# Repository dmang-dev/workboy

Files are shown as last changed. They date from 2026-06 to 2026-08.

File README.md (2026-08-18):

# WorkBoy — a modern, buildable recreation

An open recreation of Nintendo's unreleased **Game Boy WorkBoy** keyboard
accessory (Source R&D / Fabtek / Montague‑Weston, 1992): a QWERTY keyboard that
plugs into the Game Boy Link Port and turns the console into a PDA, plus a
software cartridge.

This repo contains a complete, **buildable and CI‑verified** design — firmware,
a clean‑room ROM, a DRC‑clean PCB, a 3D‑printed case, and an assembly‑ready BOM.

> **Status:** `python tests/run_ci.py` is green — 16 protocol checks + ROM,
> firmware, and case builds. The PCB autoroutes to **0 DRC violations**.

## What's here
| Path | What |
|---|---|
| [`BUILD_PLAN.md`](BUILD_PLAN.md) | the full engineering plan (start here) |
| [`WORKBOY_PROTOCOL.md`](WORKBOY_PROTOCOL.md) | the link‑port byte protocol + scan‑code table |
| `layout/` | single source of truth for the 53‑key layout (`keymap.py`) |
| `firmware/` | ATmega328P keyboard firmware (PlatformIO / avr‑gcc) |
| `rom/` | clean‑room GBDK cartridge: notepad, clock, calculator, phone book |
| `kicad/` | netlist, placed+routed board, Gerbers, CPL — see [`PCB_README.md`](kicad/PCB_README.md) |
| `case/` | parametric enclosure (OpenSCAD + build123d) |
| `tests/` | `protocol_sim.py` + `run_ci.py`; CI in `.github/workflows/` |

## Build & test
```sh
python tests/run_ci.py     # runs every check whose toolchain is installed
```
Toolchains: GBDK‑2020 (ROM), PlatformIO + avr‑gcc (firmware), build123d (case),
KiCad 10 + Freerouting (PCB). See [`BUILD_PLAN.md`](BUILD_PLAN.md) and
[`kicad/PCB_README.md`](kicad/PCB_README.md) for the full pipelines.

## How it works (one paragraph)
The Game Boy is the serial master on the link port; the WorkBoy keyboard is a
passive slave that returns one scan‑code byte per poll. So the "custom PCB" is a
small **5 V ATmega328P keyboard‑matrix controller** that speaks the documented
WorkBoy serial protocol — no level shifter needed. The protocol/scan‑codes were
reverse‑engineered by shonumi (GBE+) and re‑verified here against the real ROM.

## Console compatibility

**One 5 V design covers every console that can run a Game Boy / Game Boy Color
cartridge** — including the GBA and GBA SP, whose link port switches to **5 V**
when an 8‑bit cartridge is inserted. Only the cable plug varies.

| Works | Doesn't |
|---|---|
| DMG‑01, Pocket, Light, Color, GBA, GBA SP | **Game Boy Micro** (GBA‑only, can't run GB/GBC carts) · **Super Game Boy** (no link port) |

Full table, cable choices, and why this is **not** split into per‑console repos:
[`COMPATIBILITY.md`](COMPATIBILITY.md).

> ⚠️ GBA/SP support is documented behaviour that this project has **not yet
> verified on a bench**. Measure before trusting it.

## What you'll need to build one

Nothing here is exotic. Rough 2026 USD; the board is most of the cost.

**Console side**
| Item | Why | ~$ |
|---|---|---|
| A Game Boy that runs GB/GBC carts | the target console — see the compatibility table above | — |
| Flash cart + microSD (EZ-Flash Junior, EverDrive GB, …) | runs `rom/workboy_homebrew.gb`. SD-backed saves mean the phone book persists with **no cart battery** | 25–70 |
| A cheap DMG/GBC link cable to cut | the plug end *is* the connector — see below | 5–8 |

**The keyboard board**
| Item | Why | ~$ |
|---|---|---|
| Bare PCB from JLCPCB, qty 10 | zip up `kicad/gerber/` and upload it. ~$19.60 + shipping | 48 |
| Components per [`workboy_jlcpcb_bom.csv`](workboy_jlcpcb_bom.csv) | one 100-pc lot of each resistor value covers the run. The ATmega is 55 % of it | 39 |
| ~60× 6×6 mm THT tact switches (LCSC **C42416249**) | the 53 keys + spares. ⚠️ *Not* C720477 — that is an SMD 4×3 mm part and will not fit | 2 |
| 2×3 2.54 mm pin header | the ISP header (J2), for flashing | 1 |
| M2.5 brass heat-set inserts + screws | fasten the printed clamshell | 10 |
| *(optional)* blank tactile keycaps | nicer than printed; legends are non-standard anyway | 6 |

Ordering **10 boards** costs $86.50 all-in ($8.65/board) versus $59.75 for 5 —
28 % cheaper per board, because the engineering fee and shipping don't scale.

**Tools**
- **An ISP programmer.** An **Arduino Uno running the stock ArduinoISP sketch** is
  the cheapest route and doubles as the breadboard prototype MCU (it's a 5 V
  ATmega328P, so it talks to the DMG link directly). A USBasp works too.
  ⚠️ **An ST-Link will not work** — it speaks SWD/JTAG/SWIM, and the ATmega needs
  ISP. `firmware/platformio.ini` already ships a commented `stk500v1` block for
  the Arduino-as-ISP path.
- **A logic analyzer** (any cheap 8-channel 24 MHz sigrok/PulseView clone, ~$10) —
  verifying the SPI handshake and clock edge is the single most useful bring-up check.
- Soldering iron, solder, flux · breadboard + dupont wires · 3D printer + PETG/PLA.

**The link connector — the one part with no catalog option**
There is no reliably-purchasable bare DMG link plug. Either **cut a third-party
link cable** (most reliable — keep the 4 used wires SO/SI/SC/GND, and *meter them
before soldering*: the two ends are deliberately cross-wired, so one end's SO is
the other's SI), or **3D-print the plug** — e.g. svender's
[DMG link cable plug](https://www.thingiverse.com/thing:6924711), which uses 6 pins
harvested from female USB sockets. Breakout PCBs exist but still need a cable.

**Suggested order of purchase.** Buy the logic analyzer and a link cable first and
run the P0/P1 protocol test on a breadboard — prove the handshake before spending
on the PCB. Order boards, switches and inserts only once that works.

## Licence

**MIT** — see [`LICENSE`](LICENSE). Attribution, scope, and what is deliberately
*not* in this repo are recorded in [`NOTICE`](NOTICE).

## Legal

This is an independent, unofficial recreation. It is **not affiliated with,
endorsed by, or connected to Nintendo**, Source R&D, Fabtek, or Montague‑Weston.
"WorkBoy" and "Game Boy" are used descriptively to identify the device being
recreated and the consoles it attaches to.

The original WorkBoy ROM is leaked, copyrighted Nintendo‑licensed code — it is
**not** included here and must not be committed or distributed. The cartridge
software in `rom/` is **clean‑room**, written from the documented wire protocol.
Use the leaked ROM only for private bench reference.

The WorkBoy trademark (USPTO 74239332, filed 1992) was **abandoned in 1994**
without ever registering, and both original companies are defunct — see
[`NOTICE`](NOTICE).

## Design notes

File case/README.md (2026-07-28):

# WorkBoy case (parametric, OpenSCAD)

A starter two-piece clamshell — top plate with key cutouts + bottom tray with
PCB standoffs, heat-set screw bosses, and a rear cable slot. Defaults to
~150 × 85 mm to match the original WorkBoy footprint.

## Render / export
Install [OpenSCAD](https://openscad.org/), open `workboy_case.scad`, set `part`
and press **F6**, or from the command line:
```sh
openscad -D 'part="top"'    -o workboy_top.stl    workboy_case.scad
openscad -D 'part="bottom"' -o workboy_bottom.stl workboy_case.scad
```

## The key field is generated — do not hand-edit it

Plate cutouts come from **`layout/keymap.py`**, the single source of truth, via
`layout/gen_layout.py` → **`case/key_positions.scad`**. `workboy_case.scad`
`include`s that file and cuts one rectangle per key at its real centre, scaling
each by its own width in key units. The build123d port imports the same data
directly (`from keymap import centers`).

So both case models already carry the **real 53-key layout**: rows of
**12 / 11 / 11 / 11 / 8**, 52 keys at 1u plus the **5u space bar**, on a
12 × 5 unit field at 12 mm pitch (144 × 60 mm).

**After changing `keymap.py`, re-run the generator** or the case silently drifts
from the PCB:
```sh
python layout/gen_layout.py    # rewrites key_positions.scad, scancode_map.h, keymap.svg, key_positions.json
python tests/run_ci.py
```

## Key parameters (top of the file)
| Param | Meaning |
|---|---|
| `pitch` | key center-to-center spacing (mm) — **must match `PITCH` in `gen_layout.py`** |
| `key_gap` | plate cutout = key cell minus this (cap clearance) |
| `key_pos[]` | **generated** — `[cx, cy, width_units]` per key, origin = case centre |
| `case_h`, `wall`, `plate_th`, `floor_th` | shell dimensions |
| `standoff_h` | PCB rest height (clears THT lead tails) |
| `insert_d` | heat-set insert pocket dia — **verify against your inserts** |

## This is a starting point — refine before printing
1. **Keycap interface:** holes are sized for floating caps captured by the plate.
   Tune `cap_clear` with a one-row fit-test print before committing 53 holes.
3. **Material:** PETG for the shell (survives heat-set inserts and a warm
   console); resin for crisp legended keycaps.
4. **Fasteners:** M2.5 brass heat-set inserts in the bosses, screws from the top.
   For hidden screws, flip to inserts-in-plate / screws-from-bottom (Scheme B in
   BUILD_PLAN §5).
5. **Cable:** the rear slot is for a soldered link pigtail; add a printed strain
   relief or grommet.

## build123d model — **the board file is the single source of truth**

[`workboy_case_b123d.py`](workboy_case_b123d.py) is the maintained model. It exports
`workboy_top.stl`, `workboy_bottom.stl` and a combined `workboy_case_assembly.step`.

**Every dimension is parsed from `kicad/workboy.kicad_pcb` at build time** — the
outline, the four mounting-hole positions, the key pitch and the key-field offset.
Nothing is hard-coded, so the case cannot drift from the PCB. Change the board,
re-run this, done.

```sh
python -m venv .venv && .venv/bin/pip install build123d   # never install system-wide
python workboy_case_b123d.py
```

It refuses to export if the board does not fit, and reports the numbers it used:

```
board  : 152.000 x 106.125 mm, centre (150.0000, 89.0625) [from workboy.kicad_pcb]
case   : 160.000 x 114.125 x 22.000 mm outer
         155.200 x 109.325 mm interior (1.6 mm clearance per side)
key    : pitch 12.0 mm measured from the board; field offset (+0.0000, +19.0625)
mounts : 4 at (-72.000,-49.063), (-72.000,+49.062), (+72.000,-49.063), (+72.000,+49.062)
```

For the visual assembly it also imports `kicad/workboy_board.step` if present, and
checks that the board centres, that the through-hole leads clear the floor and that
the tallest part clears the top plate. Generate that STEP with:

```sh
kicad-cli pcb export step --output kicad/workboy_board.step kicad/workboy.kicad_pcb
```

> ⚠️ There used to be a `kicad/make_board_step.py` that produced a **placeholder
> rectangle** into that same path — and CI ran it, so it silently overwrote the real
> export. It has been removed. If you find it referenced anywhere, that reference is
> stale; use the `kicad-cli` line above.

> **The key field is not centred on the board.** The PCB carries a ~48 mm
> electronics strip below the last key row, so the key field sits **+19.0625 mm**
> from the board centre. `keymap.centers()` is origin-centred on the *key field*;
> the case is centred on the *board*. The script derives that offset from the real
> switch coordinates rather than assuming it.

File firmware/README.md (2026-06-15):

# WorkBoy keyboard firmware (ATmega328P)

Bare-metal AVR firmware that makes the controller PCB act as the WorkBoy
keyboard: a passive **SPI slave** on the Game Boy link, plus an 8×7 matrix scan.
Protocol contract: [`../WORKBOY_PROTOCOL.md`](../WORKBOY_PROTOCOL.md). Pin map:
[`../kicad/KICAD_NETLIST.md`](../kicad/KICAD_NETLIST.md).

## Pin map (matches `kicad/workboy.net`)
- **Rows** ROW0–7 = **PORTD** (PD0–PD7) — driven LOW one at a time, others hi-Z.
- **Cols** COL0–5 = PC0–PC5, COL6 = PB0 — inputs with internal pull-ups.
- **Link SPI** /SS PB2, MOSI PB3, MISO PB4, SCK PB5 (Mode 1, MSB-first).
- **LEDs** PB6 (CAPS), PB7 (NUM). **Reset** PC6. **Spare** PB1.

## Build / flash (PlatformIO)
```sh
pio run            # build
pio run -t fuses   # internal 8 MHz RC + BOD 2.7 V (needed so PB6/PB7 are GPIO)
pio run -t upload  # flash via USBasp on the ISP header (J2)
```
Program **before** attaching the link cable — the ISP pins are shared with the
link SPI lines.

No PlatformIO? Build with avr-gcc directly:
```sh
avr-gcc -mmcu=atmega328p -DF_CPU=8000000UL -Os -Wall -o workboy.elf workboy_keyboard.c
avr-objcopy -O ihex workboy.elf workboy.hex
avrdude -c usbasp -p m328p -U flash:w:workboy.hex
# fuses: internal 8 MHz, BOD 2.7 V
avrdude -c usbasp -p m328p -U lfuse:w:0xE2:m -U hfuse:w:0xD9:m -U efuse:w:0xFD:m
```

## What to verify on first bring-up
1. **SPI edge:** the code uses Mode 1 (CPOL=0, CPHA=1). If the Init reply comes
   back rotated on a logic analyzer, flip `CPHA` (see `spi_slave_init`) to Mode 3.
2. **No-key value & modifier model:** `WB_NOKEY` and the toggle-vs-shift model are
   `#define`s at the top of `workboy_keyboard.c`. Defaults match the GBE+/leaked-ROM
   convention; flip to SameBoy's (`0xFF`, held-shift) only if the real ROM rejects
   input.
3. **Matrix:** fill `SCANCODE[ROWS][COLS]` to your physical key wiring; the diode
   orientation (anode→COL) must match the scan direction (drive ROW low, read COL).

## Status
`workboy_keyboard.c` is complete and self-contained: SPI-slave state machine,
1 ms debounced matrix scan, 1 Hz software RTC, and the GPIO layer wired to the
netlist. The two things to finalize per your build are the physical `SCANCODE`
legend map and (optionally) lighting the CAPS/NUM LEDs.

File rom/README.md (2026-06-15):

# WorkBoy homebrew ROM (clean-room)

A **legally distributable** Game Boy cartridge that drives the recreated WorkBoy
keyboard over the link port. Built only from the documented wire protocol
([`../WORKBOY_PROTOCOL.md`](../WORKBOY_PROTOCOL.md)) — it contains **no leaked
Nintendo code or assets**.

> This is a **bring-up demo / foundation**, not the full 12-app suite. It proves
> the keyboard works end-to-end: link handshake, a notepad that echoes typed
> characters, NUM-mode toggling, and an RTC timestamp from the keyboard's clock.
> Extend it app-by-app from here.

## Files
| File | Role |
|---|---|
| `src/workboy_link.c/.h` | GB **master**-side link driver (the 4 commands) |
| `src/scancodes.c/.h` | scan-code → ASCII map (kept identical to the firmware) |
| `src/phonebook.c/.h` | **phone book stored in the 32 KB battery SRAM** (add / list / scroll) |
| `src/main.c` | home: notepad + clock + `App-7` opens the phone book |
| `Makefile` | GBDK-2020 build → `workboy_homebrew.gb` (MBC1+RAM+BATTERY) |

> **Builds clean** with GBDK-2020 → a 128 KB MBC1+RAM+BATTERY image (verified
> header: cart `0x03`, 128 KB ROM, 32 KB SRAM). The phone book uses MBC1
> RAM-banking mode across all four 8 KB banks (128-byte records, up to 255
> entries) and persists on a battery-backed cart.

## Build
1. Install **GBDK-2020** (<https://github.com/gbdk-2020/gbdk-2020/releases>).
2. Build, pointing at your install:
   ```sh
   make GBDK_HOME=/opt/gbdk          # Linux/macOS
   make GBDK_HOME=C:/gbdk            # Windows (forward slashes)
   ```
3. Output: `workboy_homebrew.gb`.

## Run
- **EverDrive GB / EZ-Flash Jr.:** copy `workboy_homebrew.gb` to the microSD and
  pick it from the menu. Saves use the cart's battery SRAM.
- **Repro cart:** flash to an **MBC1 + RAM + BATTERY** cartridge (the Makefile sets
  cart type `0x03`, 32 KB SRAM). A no-mapper 32 KB cart will **not** work.
- Connect the recreated keyboard to the link port, power it (USB-C/battery), and
  reset. You should see `Keyboard: OK`, then typing echoes on screen; press the
  Clock app-key to print the time.

## Protocol notes baked in
- GB is the **master** (internal clock, `SC_REG = 0x81`). Responses are pipelined
  by one transfer — `wb_poll_key()` polls twice and returns the second byte.
- Commands: `0x52` Init→`0x44`, `0x4F` Poll→scancode, `0x44` Read-RTC→42 bytes,
  `0x57` Write-RTC (not used by this demo).
- `wb_xfer()` has a spin-guard so a missing/unpowered keyboard can't hang the ROM.

## Validate on a logic analyzer first
If the handshake fails on real hardware, check the SPI edge convention against the
keyboard firmware (Mode 1 vs Mode 3) and confirm the keyboard's no-key value is
`0x00` (GBE+) — both are `#define`-switchable on the firmware side.

## Extending toward the full suite
Add apps as screens driven by the app-launch scancodes (`0x01`–`0x09`). Persist
data in the 32 KB battery SRAM (`ENABLE_RAM`, write to `0xA000`+ banks). Re-create
the calculator / phone book / calendar logic from scratch — do **not** copy the
leaked ROM's code or data.

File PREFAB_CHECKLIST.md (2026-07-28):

# Pre-fabrication checklist

**Can I order a board yet?** Work down this list. Anything marked 🔴 will cost you
a board if you skip it.

> **Status: not yet ordered. Nothing here has been built.** Everything below is
> from design review, not from an assembled unit.

> ### Verification pass 2026-07-28
>
> The three original blockers were investigated against the real KiCad files with
> `kicad-cli` 10.0.5 and `pcbnew`. **Two were false alarms. The third is worse than
> written.** Two new blockers were found that were not on the list at all.
>
> **The bare PCB is electrically sound and could be fabricated today** — DRC is
> genuinely clean (0 violations, 0 unconnected, 886 tracks, 60 vias) and every net
> checked lands where the netlist says. What blocks an order is **mechanical**:
> no mounting holes, and a case built to the wrong size.
>
> Confidence is *not* uniform below — each item says how it was established.

---

## 🔴 Blocking — fix before uploading gerbers

### 1. ~~The board has no mounting holes at all~~ ✅ **RESOLVED 2026-07-28 — four added**

*Was: `grep -c MountingHole` → 0, while `BUILD_PLAN` promised 4× M2.5 and the case
drilled four standoffs. The placeholder's holes at (±61, ±28.5) were fictional.*

Four `MountingHole:MountingHole_2.7mm_M2.5` (**plain NPTH, no copper**) are now
placed, 4.0 mm inset from the `Edge.Cuts` centreline at each corner, symmetric
about the board centre **(150.0, 89.0625)**:

| Ref | Corner | Position (mm) |
|---|---|---|
| **H1** | top-left | **(78.000, 40.000)** |
| **H2** | top-right | **(222.000, 40.000)** |
| **H3** | bottom-left | **(78.000, 138.125)** |
| **H4** | bottom-right | **(222.000, 138.125)** |

**Hole spacing: 144.000 × 98.125 mm** — these are the numbers the case standoffs
must use.

Positions were chosen by scanning clearances against every pad, track, via and part
body. Insets of 4.0–5.5 mm all pass; **6.0 mm fails** because the top-right hole
starts fouling **SW12**. 4.0 mm was taken as it maximises component clearance at
that tightest corner:

| | copper clr | part-body clr | edge clr |
|---|---|---|---|
| H1 | 7.071 mm (SW1) | 6.329 mm | 4.000 mm |
| **H2** | **4.607 mm (SW12)** | **4.475 mm** ← tightest | 4.000 mm |
| H3 | 9.318 mm (R11) | 9.071 mm | 4.000 mm |
| H4 | 24.934 mm (J3) | 22.674 mm | 4.000 mm |

A 5 mm case post needs 2.5 mm of body clearance, so the worst case leaves **1.98 mm
of margin**. Hole edge sits 2.65 mm from the board edge.

**Verified after the change:**
- `kicad-cli pcb drc --severity-all --exit-code-violations` → **0 violations, 0
  unconnected, 0 footprint errors**, exit 0
- Board outline **unchanged** (73.925–226.075 × 35.925–142.200 incl. stroke)
- Drill file carries tool **`T6C2.700` with exactly 4 hits** at those coordinates
- Holes are marked exclude-from-BOM and exclude-from-position-files, so the **CPL
  still lists 131 parts** and `workboy_jlcpcb_bom.csv` is byte-unchanged
- H1–H4 added to `generate_workboy_netlist.py` (135 components, zero net nodes) so
  a future netlist re-import **cannot silently delete them**

> ⚠️ The right-hand edge only has **2.05 mm** of free border (J3 runs close to it) —
> there is no room for a fifth hole mid-span on that side. The corners are the only
> viable positions.

### 2. ~~The case is sized for 144 × 78~~ ✅ **RESOLVED 2026-07-28 — case rebuilt from the board**

*Was: three different board sizes in the docs and none of them right. The case
interior was **155.2 × 71.2 mm** for a **152.000 × 106.125 mm** board — it overran
by 34.9 mm in depth and was 30 mm deeper than the case's whole outer envelope. The
placeholder never fitted either, so the model was unvalidated, not merely stale.*

`case/workboy_case_b123d.py` was rewritten to **parse `kicad/workboy.kicad_pcb` at
build time**. The outline, the four mounting-hole positions, the key pitch and the
key-field offset are all read from the board — nothing is hard-coded, so the case
cannot drift from the PCB again. It **refuses to export** if the board does not fit.

| | Old | New |
|---|---|---|
| Outer | 160 × 76 × 22 mm | **160.000 × 114.125 × 22.000 mm** |
| Interior | 155.2 × 71.2 mm | **155.200 × 109.325 mm** |
| vs board 152.000 × 106.125 | ✗ 34.9 mm short | ✅ **1.600 mm clearance per side** |
| Standoffs | (±61, ±28.5) — matched no real hole | **(±72.000, ±49.0625)** = H1–H4 |
| Sized from | key field | **the board outline** |

**Verified independently** (re-derived from the board and the exported solids, not
from the script's own claims):

- **Key cutout alignment: worst mismatch 0.000000 mm across all 53 keys.** Every
  cutout is centred on its switch.
- Board centring error **0.0000 mm** in both axes.
- **4.095 mm** of air under the protruding through-hole leads (they reach 1.905 mm
  below the PCB — the old model never accounted for them).
- **1.865 mm** headroom between the tallest part (18.135 mm) and the top plate.
- `tests/run_ci.py` → `case-export PASS`.

Two things the rewrite had to fix beyond size:

- **The key field is not centred on the board.** There is a ~48 mm electronics strip
  below the last key row, so the field sits **+19.0625 mm** from the board centre.
  `keymap.centers()` is origin-centred on the *key field*, the case on the *board*.
  The offset is now derived from the real switch coordinates.
- **Screw bosses and PCB standoffs had to merge.** With 1.6 mm of clearance there is
  no room for separate corner bosses beside a board that fills the interior — they
  would collide with it. One M2.5 screw per corner now passes through the top plate,
  through the PCB hole, into an insert in the boss, so the same fastener closes the
  case and retains the board. The clearance scan behind §1 already proved a 7 mm
  boss fits at all four holes.

> 🔴 **`kicad/make_board_step.py` has been deleted, and this mattered.** It wrote a
> placeholder rectangle to `kicad/workboy_board.step` — **and `tests/run_ci.py` ran
> it on every CI run**, silently overwriting the real exported board with a 144 × 78
> rectangle. Regenerate the real one with:
> ```sh
> kicad-cli pcb export step --output kicad/workboy_board.step kicad/workboy.kicad_pcb
> ```

> ⚠️ **Remaining case work is connector access, not fit** — see §7.

### 3. ~~J3 USB-C pad names are unverified~~ ✅ **RESOLVED — false alarm**
*Established with `pcbnew` against the placed footprint, and by diffing the board's
footprint copy against the KiCad 10 library `.kicad_mod`. This item had full
adversarial review; nothing was overturned.*

The old text was wrong on both counts. The netlist never used GCT `USB4085` naming
(`generate_workboy_netlist.py:44` declares
`Connector_USB:USB_C_Receptacle_HRO_TYPE-C-31-M-12`, which is exactly what is placed
at `workboy.kicad_pcb:4783`), and the shield is called **`SH`** in both — no
KiCad 10 `Connector_USB` footprint uses an `S1` pad at all.

All 10 referenced pad names exist and carry the intended net:

| Net | Pads |
|---|---|
| GND | A1, A12, B1, B12, + 4× SH |
| VBUS | A4, A9, B4, B9 |
| USB_CC1 / USB_CC2 | A5 / B5 |

Sink topology is valid (5.1 kΩ Rd on both CC lines), and D54's SS14 is oriented
correctly — pad 2 (anode) on VBUS, pad 1 (cathode) on +5 V. `A6/A7/A8/B6/B7/B8`
are intentionally netless: this is a power-only connector and the ATmega328P has no
native USB.

> **Still worth 30 seconds before ordering:** that **LCSC C165948** really is the
> HRO TYPE-C-31-M-12 is a vendor-catalogue fact that cannot be checked from these
> files. Compare the LCSC land pattern against the footprint before you buy.

> **Do not add a 16 MHz crystal later without revisiting D54.** The Schottky drops
> ~0.4–0.5 V, so +5 V sits below VBUS. Harmless now (the MCU runs on its internal
> oscillator — there is no crystal in the netlist), but at 16 MHz a 4.75 V source
> minus the drop falls under the 4.5 V minimum.

### 4. ~~Tact switch pad numbering~~ ✅ **RESOLVED** — but the **BOM part is wrong** 🔴
*⚠️ Confidence caveat: the adversarial reviewers for this item all failed to run
(spend limit). The reasoning below is from a single investigation plus the cited
datasheet — **it has not been independently cross-checked.***

The pad-numbering worry was well founded but the wiring is **correct**.
`SW_PUSH_6mm` in KiCad 10.0.5 does use duplicated numbers (four pads: `1,1,2,2`),
and the grouping is right: same-numbered pads sit **6.5 mm apart** on a common Y
(`SW_PUSH_6mm.kicad_mod:290-315`), matching the Omron B3F terminal arrangement
where the tied legs span the long side. The switch closes across the 4.5 mm gap —
so netlist pads 1 and 2 are genuinely **across the contacts**, not shorted.

Every footprint also carries `(duplicate_pad_numbers_are_jumpers no)`, so KiCad
required real copper between each tied pair rather than trusting the leadframe —
and that copper is present. A single bad solder joint per pair will not kill a key.

✅ **BOM part corrected 2026-07-28 — `C720477` was indeed the wrong part.**

Checked on LCSC: **`C720477` is XUNPU `TS-1088-AR02016`, package "SMD,4x3mm",
surface mount, 2 terminals.** Wrong size, wrong mount type, wrong terminal count —
all 53 switches were specified as a part that cannot be fitted to this footprint.

Replaced with **`C42416249` — SHOU HAN `SH-6X6X8H-CJ`**:

| | |
|---|---|
| Package | **`DIP-4P,6x6mm`** — through-hole, 4 legs |
| **Lead spacing** | **6.5 × 4.5 mm** — matches `SW_PUSH_6mm` exactly |
| Body / height | 6 × 6 mm, 8 mm actuator |
| Life | 100,000 cycles · SPST · 50 mA · 12 V |
| Stock / price | 8,480 · ~$0.0124 ea @ 20+ (≈ **$1.30 for 100**) |

8 mm was chosen because the case already models the switch ~8.5 mm above the PCB.
**The whole SH-6X6X\*H-CJ family shares the identical 6.5 × 4.5 mm footprint** at
4.3 / 5.5 / 6.5 / 8 / 9 mm, so the actuator height can be re-picked when the keycaps
are designed **without touching the board** — only the BOM line changes.

> The `Footprint` column was also wrong (`SW-TH-6.0x6.0`, a name matching nothing);
> it now carries LCSC's own `DIP-4P,6x6mm` string.

#### 🔴 And a second wrong part number: J2

Found while costing the BOM. **`C2718` is an onsemi `FDA50N50` — a 500 V, 48 A
N-channel MOSFET**, not a 2×3 pin header. Confirmed on the LCSC product page
(category *Discrete Semiconductors → Transistors → FETs, MOSFETs*).

Replaced with **`C42431837` — JXTCONN `PH2.54-2X3P-H25`**: category *Headers, Male
Pins*, 2×3 six-pin dual row, 2.54 mm pitch, through-hole, gold-plated, 3 A / 1 kV,
39,180 in stock, **$0.0293 ea @ 20+**.

> **Two of the fourteen BOM lines pointed at parts that could not be fitted.** Both
> were plausible-looking C-codes that nobody had opened. If any other line matters
> to you, open its LCSC page before ordering — the footprints are verified against
> the real land patterns, but a part *number* is only as good as the last person who
> checked it.

### 4b. 🔍 Full BOM audit — **every line opened on LCSC (2026-07-28)**

Prompted by two bad part numbers in a row. All 14 lines checked for *identity,
value, package and availability* — not just existence.

| Line | LCSC | What it actually is | Verdict |
|---|---|---|---|
| U1 ATmega328P-AU | `C14877` | Microchip ATMEGA328P-AU · 5,662 stock · $2.14 | ✅ |
| C1–C4 100nF 0402 | `C1525` | Samsung CL05B104KO5NNNC · 100nF **0402** 16 V X7R · 1.39 M | ✅ |
| C5,C6 10µF 0805 | `C15850` | Samsung CL21A106KAYNNNE · 10µF **0805** 25 V X5R · 295 k | ✅ |
| D1–D53 1N4148W | `C2099` | JSCJ 1N4148W **SOD-123** · 32,050 · $0.0124 | ✅ |
| D54 SS14 | `C2480` | MDD SS14 **SMA** · $0.019 (MOQ 50) | ✅ |
| J3 USB-C | `C165948` | **Korean Hroparts TYPE-C-31-M-12** · 246,285 · $0.17 | ✅ *(also settles §3)* |
| SW1–53 tact | `C42416249` | SHOU HAN SH-6X6X8H-CJ · DIP-4P 6×6 · 8,480 | ✅ *(fixed, §4)* |
| J2 ISP header | `C42431837` | JXTCONN PH2.54-2X3P-H25 · 2×3 male THT · 39,180 | ✅ *(fixed, §4)* |
| R1–R3 10k 0402 | ~~`C25744`~~ → **`C60490`** | was UNI-ROYAL 0402WGF1002TCE — right part, **out of stock** | ✅ **replaced** |
| R4–R6 220R 0402 | ~~`C25091`~~ → **`C112291`** | was UNI-ROYAL 0402WGF2200TCE — right part, **out of stock** | ✅ **replaced** |
| R7–R9 1k 0402 | ~~`C11702`~~ → **`C106235`** | was UNI-ROYAL 0402WGF1001TCE — right part, **out of stock** | ✅ **replaced** |
| R10,R11 5.1k 0402 | ~~`C25905`~~ → **`C105872`** | was UNI-ROYAL 0402WGF5101TCE — right part, **out of stock** | ✅ **replaced** |
| LED1 red "0805" | ~~`C2286`~~ → **`C2295`** | was KENTO **KT-0603R — 0603**, not 0805 | 🔴 **wrong package — fixed** |
| LED2,3 green "0805" | ~~`C72043`~~ → **`C2297`** | was EVERLIGHT 19-217 — **0603** *and* unavailable | 🔴 **wrong package — fixed** |

#### 🔴 Both LEDs were the wrong package

`C2286` and `C72043` are **0603** parts, but the board has **0805** land patterns
(`LED_SMD:LED_0805_2012Metric`). A 0603 body hand-solders onto 0805 pads, but in
reflow it risks tombstoning and misplacement — pick-and-place positions to the
part's own body, not the pad.

Replaced with the same manufacturer's genuine 0805 parts, both well stocked:
**`C2295` KT-0805R** (red, 101,200) and **`C2297` KT-0805G** (green, 1,996,800).

#### ⚖️ The 0402 resistors depend on **who assembles the board**

The two catalogues disagree, and the right part number is different for each path:

| | LCSC retail (hand-buy) | JLCPCB library (PCBA) |
|---|---|---|
| **UNI-ROYAL `0402WGF*TCE`** | ❌ out of stock | ✅ **Basic**, stocked (1.1–2.1 M) |
| **YAGEO `RC0402FR-07*`** | ✅ in stock (0.2–1.4 M) | ⚠️ **Extended** (per-part fee) |

Electrically identical — **0402, ±1 %, 62.5 mW, 50 V, ±100 ppm/℃, thick film** — so
this is purely a sourcing choice.

**`workboy_jlcpcb_bom.csv` carries the UNI-ROYAL parts**, because it is the JLCPCB
*assembly* BOM and `BUILD_PLAN` outsources SMT. JLCPCB sources from its own library,
where these are Basic and in stock, so LCSC's retail shortage is irrelevant and you
avoid four Extended-part fees.

| Ref | Value | PCBA (in the BOM) | Hand-build alternative |
|---|---|---|---|
| R1–R3 | 10 kΩ | **`C25744`** 0402WGF1002TCE | `C60490` RC0402FR-0710KL |
| R4–R6 | 220 Ω | **`C25091`** 0402WGF2200TCE | `C112291` RC0402FR-07220RL |
| R7–R9 | 1 kΩ | **`C11702`** 0402WGF1001TCE | `C106235` RC0402FR-071KL |
| R10,R11 | 5.1 kΩ | **`C25905`** 0402WGF5101TCE | `C105872` RC0402FR-075K1L |

> **If you hand-assemble, swap in the right-hand column** — LCSC cannot sell you the
> left-hand parts today. MOQ there is 100 in multiples of 100, ~$0.55 per value.

> 🪤 **The stock trap:** every LCSC product page has `... | In Stock | LCSC
> Electronics` in its `<title>` as **static SEO boilerplate — even for
> out-of-stock parts**. It fooled this review once. Read stock from the page body,
> where an unavailable part shows "Out of Stock" and a "Notify Me" button instead of
> "Add to Cart".

> **Tally: 8 of 14 lines were wrong.** Four named a part that could not be fitted
> (2 outright wrong parts, 2 wrong package) and four named parts that could not be
> bought. All eight are now corrected and individually verified. The footprints had
> been checked against real land patterns all along — it was the *part numbers* that
> nobody had ever opened.
>
> **Every line is now confirmed against its own LCSC page**, with stock read from
> the page body. No board change came out of any of it: the `.kicad_pcb` carries no
> LCSC part numbers, so the gerbers, drill and CPL were never affected.

### 4c. JLCPCB **Basic vs Extended** — every SMT part checked (2026-07-28)

Extended parts carry a per-unique-part loading fee, so this drives assembly cost
more than the components do. Checked directly in JLCPCB's parts library:

| Part | LCSC | Class | JLC stock | @1+ |
|---|---|---|---|---|
| 100nF 0402 | `C1525` | ✅ **Basic** | 46,782,818 | $0.0053 |
| 10 µF 0805 | `C15850` | ✅ **Basic** | 10,801,486 | $0.1191 |
| SS14 | `C2480` | ✅ **Basic** | 2,084,080 | $0.0189 |
| Green LED 0805 | `C2297` | ✅ **Basic** | 2,977,165 | $0.0162 |
| 10 kΩ 0402 | `C25744` | ✅ **Basic** | — | — |
| 220 Ω 0402 | `C25091` | ✅ **Basic** | — | — |
| 1 kΩ 0402 | `C11702` | ✅ **Basic** | 1,120,826 | — |
| 5.1 kΩ 0402 | `C25905` | ✅ **Basic** | 2,109,090 | — |
| **ATmega328P-AU** | `C14877` | ⚠️ Extended | 29,242 | $2.4159 |
| **1N4148W** ×53 | `C2099` | ⚠️ Extended | 61,717 | $0.0123 |
| **USB-C** | `C165948` | ⚠️ Extended | 264,067 | $0.1843 |
| **Red LED 0805** | `C2295` | ⚠️ Extended | 102,716 | $0.0115 |

**8 Basic, 4 Extended.** Keeping the UNI-ROYAL resistors (§4) rather than the YAGEO
ones cut Extended from 8 to 4 — worth roughly $12 in loading fees, i.e. more than
the bare PCBs cost.

The four that remain are hard to avoid: the MCU, the USB-C receptacle and the
switching diode have no Basic equivalent for this design. Only the **red LED** is
casually swappable — its green sibling `C2297` *is* Basic, so if you want one fewer
Extended line, use a Basic red 0805 or make the power LED green too.

> 🪤 **JLCPCB's page title lies the same way LCSC's does.** Every search renders
> `No Results Found for <code>` into `<title>` **before** the client-side fetch
> returns, then the body fills in with the real hit. Judging by the title reports a
> part as missing when it is right there. This produced a wrong conclusion earlier in
> this very review — the UNI-ROYAL resistors were reported absent from JLCPCB's
> library when they are in fact **Basic and stocked**. Read the body, not the title.

> Cheap physical settle: put a DMM across one switch before soldering 53. The legs
> **6.5 mm** apart must beep **unpressed**; the legs **4.5 mm** apart must be open
> until pressed.

---

## 🟡 Decide before ordering

### 4. Which link connector?

> ### ✅ **FINAL for rev A (2026-07-28): ship J1 only. J4 and J5 are both deferred.**
>
> **This is what the board already is** — `EMIT_LINK_SOCKET` and `EMIT_LINK_EDGE`
> are both `False`, so J4 and J5 have never appeared in any netlist or board. The
> exported gerbers, drill, CPL and BOM in this repo are **correct as they stand and
> need no re-export** for this decision.
>
> **Why J1 only.** J4 is not free in the way it first looked. It costs nothing in
> *board area*, but it does cost a **footprint that does not exist and cannot be
> drawn without the physical part in hand** — you must buy an EXT socket, measure
> it, draw `workboy:GB_EXT_Socket_6P`, re-import, place, route, re-run DRC and
> re-export. That is the entire remaining critical path for rev A, in service of a
> connector whose only benefit over J1 is cable convenience. A soldered pigtail
> works on day one.
>
> **Rev A proves the design; rev B can add the socket** once a real board has shown
> the protocol works end to end — and by then the socket can be measured against a
> board that exists.
>
> **J5 (board-edge tongue) stays parked** for the reasons below: it forces an
> outline change, wants ENIG (**~1.5–2.0×** the bare-board line vs HASL) because an
> inserted edge wears, and — decisively — it plugs the board *rigidly into the
> console with no cable*, which is wrong for a keyboard you sit and type on.
>
> The full analysis for both is kept here and in `generate_workboy_netlist.py`, and
> the netlist support is already written and inert, so revisiting either needs no
> re-research.

**What this means practically:** populate **J1**, a 1×6 0.1″ header, and attach a
cut link cable as a pigtail. Meter it first — see the warning at the end of this
file, reversed SI/SO is a top failure mode.

All three options land on the **same six nets**; you populate exactly one. Wiring
them in parallel would be electrically free — the cost is footprint work, not area.

| | **J1** — 1×6 0.1″ header ✅ **rev A** | **J4** — real EXT socket ⏸ rev B | **J5** — board-edge tongue ⏸ parked |
|---|---|---|---|
| Status | **shipping — on the board now** | needs footprint drawn | needs footprint **+ outline** |
| Attaches via | soldered cut-cable pigtail | **any standard link cable** | plugs straight into the console |
| Part cost | ~$5–8 (cable to cut) | ~$3–10 (repair part) | **$0 — no part** |
| Board outline | unchanged | unchanged | ⚠️ **changes it** |
| Plating | HASL fine | HASL fine | ⚠️ wants **ENIG** or pads wear |
| Thickness | any | any | ⚠️ socket is ~1.2 mm nominal; **1.6 mm is tight** |
| Ergonomics | permanent tail | best — normal cable | rigid, board hangs off the console |

**J4 — deferred to rev B. Notes kept.** It changes nothing about the outline,
plating or thickness, so it can be added later at no cost to the board. What it
needs is a **footprint drawn from a physical socket**, which is why it is not in
rev A.

**J5 — parked. Notes kept for a possible rev B.**

Not free despite costing no parts:

- **Outline change** — the tongue protrudes, so the case must be re-fitted and the
  board edge redrawn.
- **Finish** — ENIG at **~1.5–2.0×** the bare-board line (HASL is JLCPCB's free
  default). Hard "gold fingers" is **~3.0–5.0×** plus bevelling, and is meant for
  thousands of insertion cycles — overkill for a connector used dozens of times.
  ENIG also *benefits the whole board* given the TQFP-32 and 0402s, so it isn't
  purely a J5 tax. Selective finish (ENIG pads + hard gold fingers) exists if ever
  needed.
- **Thickness is a fit issue, not a cost one** — 1.6 mm is JLCPCB's free default;
  the socket is nominally ~1.2 mm, so 1.6 mm is a tight insert.
- **Ergonomics decided it** — the board plugs rigidly into the console with no
  cable. Fine for a compact direct-attach variant; wrong for a keyboard.

If revisited: put the tongue on a **break-off tab** (mouse-bites / V-score) so one
fab run yields both variants, and order **ENIG — skip hard gold**. The netlist
support is already written and inert behind `EMIT_LINK_EDGE = False`.

**To enable J4:** buy an EXT socket (sources in [`COMPATIBILITY.md`](COMPATIBILITY.md)),
measure it, draw `workboy:GB_EXT_Socket_6P`, set `EMIT_LINK_SOCKET = True`.

**To enable J5:** draw `workboy:GB_EXT_EdgeTongue_6P` (3 pads top + 3 bottom, ~6 mm
tongue) *and* edit the board outline to match, set `EMIT_LINK_EDGE = True`, and
order with ENIG. Bevelling the tongue edge (JLCPCB "gold fingers", extra cost)
makes insertion much kinder.

> ⚠️ **Editing the netlist does not change the board.** After re-running the
> generator you must import the netlist in the KiCad PCB editor, place and route
> the new part, re-run DRC, and re-export gerbers + CPL.

> ✅ **Resolved 2026-07-28 — rev A ships J1 only** (see the decision box above).
> The repo previously recorded a "land J1 + J4" decision it had never carried out;
> the record now matches the board.
>
> For the record, so the old wording is not resurrected: the note that the gerbers
> "were produced *before* J4 existed" had its premise backwards. It implied the
> exports needed refreshing. They did not — **J4 never existed at all**, and the
> exports were already current. The board carries three `J` designators: J1, J2, J3.

### 5. ~~Board size vs. the cost tier~~ ✅ **QUOTED 2026-07-28 — ordering 10**

> ### 📦 **Decision: order 10 boards, not 5.**
> $86.50 all-in, **$8.65/board** — 28 % cheaper per board than ordering 5, for
> $26.75 more total. The five extra boards cost ~$5.35 each.

Live JLCPCB instant quote at **152 × 107 mm**, 2-layer, FR-4 TG135, 1.6 mm,
HASL (with lead), 1 oz, green, flying-probe tested:

| Line item | 5 pcs | **10 pcs (chosen)** |
|---|---|---|
| Engineering fee | $4.00 | **$4.00** |
| Board | $7.80 | **$15.60** |
| Build time (2 days) | $0.00 | **$0.00** |
| **PCB subtotal** | $11.80 | **$19.60** |
| Shipping — DHL Express (DDP), 2–4 days | $27.92 | **$28.06** |
| Components (LCSC, with volume breaks) | $20.03 | **$38.84** |
| **Total** | $59.75 | **$86.50** |
| **Per board** | $11.95 | **$8.65** |

**Why 10 is the sweet spot.** The fixed costs barely move: the engineering fee is
flat $4.00 and shipping rose **14 ¢** going from 5 to 10 boards. Board cost is
linear at ~$1.56 each. So at qty 5 you pay $7.94/board for PCB + shipping of which
**$7.18 is fixed overhead** — at 10 that halves.

| Qty | PCB + shipping | Parts | Total | Per board |
|---|---|---|---|---|
| 5 | $39.72 | $20.03 | $59.75 | $11.95 |
| **10** | **$47.66** | **$38.84** | **$86.50** | **$8.65** |
| 20 | $64.58 | $77.69 | $142.27 | $7.11 |
| 30 | $81.58 | $116.53 | $198.11 | $6.60 |

**The knee is at 10.** 5→10 saves $3.30/board; 10→20 only another $1.54, and 20→30
just $0.51 — past 10 the fixed costs are amortised and you are mostly buying parts
at near-flat prices.

Qty 10 also **removes the MOQ waste**: you need 530 diodes and 530 switches, so the
100-piece minimums that were mostly scrap at qty 5 get used, and the diodes cross
the 300+ price break ($0.0124 → $0.0101).

**The size penalty is only $7.80.** The board does leave JLCPCB's ≤100 × 100 mm
bracket on both axes, but that is the entire cost of it — the identical 5-pc order
at 100 × 100 mm quotes **$4.00** (board free, engineering fee only). Going to 1.61×
the area is not a tier jump worth redesigning around.

> 💡 **Shipping is the real cost — $27.92, over twice the PCBs.** That figure is
> DHL Express (DDP) and is only an estimate; slower/cheaper methods normally exist
> and the number depends on destination. The quote page was also showing "Save
> $30.00 / Save $20.00" coupons. **If cost matters, attack shipping, not board
> area.**

#### ⚠️ The PCB quote is the **bare board only** — no parts, no assembly

Components are a separate LCSC order. Every price below was read off the vendor
page during the 2026-07-28 audit:

| Item | LCSC | Qty/board | Unit | Per board |
|---|---|---|---|---|
| **ATmega328P-AU** | C14877 | 1 | $2.14 | **$2.14** |
| 1N4148W diode | C2099 | 53 | $0.0101 @300+ | $0.54 |
| Tact switch | C42416249 | 53 | $0.0124 | $0.66 |
| 10 µF 0805 | C15850 | 2 | $0.1004 | $0.20 |
| USB-C receptacle | C165948 | 1 | $0.1349 @100+ | $0.13 |
| LEDs ×3 | C2295 / C2297 | 3 | ~$0.012 | $0.04 |
| SS14 Schottky | C2480 | 1 | $0.019 | $0.02 |
| ISP header | C42431837 | 1 | $0.025 @200+ | $0.03 |
| 11 resistors + 4× 100nF | — | 15 | ~$0.005 | $0.08 |
| | | | **≈ $3.88/board at qty 10** | |

**The MCU alone is 55 % of the parts cost.** Everything else together is under
$1.75, because the two 53× lines are cheap in bulk.

> **SMT assembly is not included in any of the above.** If you want JLCPCB to place
> the MCU, passives, diodes, LEDs and USB-C rather than hand-soldering 0402s and a
> TQFP-32, that is their PCBA service, quoted separately — see §6. The 53 switches
> and J1 are hand-soldered either way. Note the ~$12 of Extended-part loading fees
> (§4c) is a **per-order** cost, so it also halves per board at qty 10.

> **Shipping is the single largest line at $28.06** — more than the PCBs. It barely
> moves with quantity, which is exactly why 10 beats 5. LCSC ships separately again;
> both vendors share a parent but not a parcel.

If you ever *do* want to shrink it, the lever is the key pitch driving the outline —
nothing electrical changes. The real pitch is **12.0 mm**, measured from the switch
coordinates, *not* the "~10 mm" quoted in `BUILD_PLAN`; the 53 switches sit on an
exact 12.0 mm grid spanning 132 × 48 mm.

> Quoted from dimensions, not from an upload. Once the real gerbers are parsed the
> figure can move slightly — but the board is well inside standard capabilities
> (2-layer, 0.25 mm track, 0.15 mm clearance, 0.3 mm drill), so no special-case
> surcharge is expected.

### 6. Assembly split — outsource the switches or not?
- **SMT only** (recommended in `BUILD_PLAN`): JLCPCB does the MCU, passives, 53
  diodes, LEDs, USB-C. You hand-solder 53 tact switches + the connector.
- **SMT + THT**: adds **$3.50 labour + ~$0.0017/joint + possibly ~$3 unique-part
  fee** ⇒ roughly **$4–7 more** for ~106 joints. Small enough that outsourcing is
  reasonable if you'd rather not do the repetition.

Either way the **link connector is consigned or hand-soldered** — it is excluded
from `workboy_jlcpcb_bom.csv` on purpose.

### 7. ~~The connectors sit inland~~ ✅ **RESOLVED 2026-07-28 — J3 moved to the right edge**

*Was: J3 sat **16.07 mm inside** the outline, so no USB-C plug could reach it —
you would have needed a 16 mm channel through the case wall.*

J3 is now **flush with the right edge**, rotated 90° so the mating face points
outward, body front on the outline and the courtyard overhanging by 0.525 mm (normal
for an edge-mounted connector). It is a real plug-through port.

| | Before | After |
|---|---|---|
| J3 → right edge | 16.07 mm inland | **−0.525 mm (overhangs)** |
| R11 (CC2 pulldown) → J3 | 138.31 mm | **9.37 mm** |
| D54 (VBUS Schottky) → J3 | 131.51 mm | **12.35 mm** |
| Total VBUS copper | ~112 mm across the board | **13.7 mm** |

The support cluster moved with it, which fixed a second latent problem. `gen_pcb.py`
placed support parts with a **row-wrapping flow**, and the `["J3","R10","R11","D54"]`
group happened to straddle a wrap — stranding the CC2 pulldown and the VBUS diode on
the far side of the PCB and dragging the unfused power input across the whole board.
That was an artifact of the layout algorithm, not a decision. The cluster is now
placed explicitly.

**J1 and J2 were never a problem** and are unchanged: J1 (9.47 mm in) is a soldered
pigtail — a wire exit, not a plug — and J2 is a programming header used once with the
lid off.

**Verified after the move:** DRC **0 violations, 0 unconnected, 0 footprint errors**;
board outline unchanged at 152.000 × 106.125 mm; 135 footprints, 1011 track/via
objects; drill still carries 4× `T6C2.700`; CPL still 131 parts. Case regenerates
identically and now cuts its **J3 port and J1 slot from the real connector
coordinates** rather than hard-coded ones.

> The board outline is now **pinned** in `gen_pcb.py` (`BX0..BY1`) instead of being
> derived from the bounding box of whatever happens to be placed. Deriving it meant
> moving any single part could silently resize the board — and the size is
> load-bearing for the case, the mounting holes and the quote. The placement is
> asserted to fit inside it instead, and the script refuses to write a board that
> overflows.

---

## ✅ Already verified

- **Clean-room ROM** builds (GBDK-2020 → 128 KB MBC1+RAM+BATTERY). No leaked code.
- **Key layout is real**: 53 keys, rows of 12/11/11/11/8, 5u space bar, generated
  from `layout/keymap.py` into both the case and the PCB placement.
- **Pin budget closes exactly** — 18/18 GPIO with zero spare.
- **DRC is genuinely clean** — re-run 2026-07-28 with `kicad-cli pcb drc
  --severity-all` against the current board: **0 violations, 0 unconnected, 0
  footprint errors**, empty exclusions, 886 track segments and 60 vias, so it is
  really routed. *(Caveat: `--schematic-parity` cannot run — there is no schematic,
  the netlist is generated. Board-vs-netlist agreement was checked by comparing
  pads, not by DRC.)*
- **J3 USB-C is correctly wired** — see §3. All pads resolve, sink topology valid.
- **Switch pads 1/2 are across the contacts**, not shorted — see §4.
- **Export artefacts are current, not stale** — gerbers, drill and the zip all
  reproduce byte-identically from the present board.
- **BOM/CPL parity**: CPL lists all 131 designators, BOM lists 130 — J1 is omitted
  deliberately (consigned/hand-soldered). Harmless, but worth a note on the order
  so it does not trigger an engineering query.
- **Electrically correct for every console that runs a GB/GBC cartridge** — all of
  them drive the link at 5 V, so no level shifter. See `COMPATIBILITY.md`.
- **Licence + attribution** in place (`LICENSE`, `NOTICE`).

---

## Order of operations

**Mechanical first — everything that changes copper must happen before the order.**

1. ~~Add mounting holes~~ ✅ **done** (§1) — H1–H4, DRC clean, all artefacts
   re-exported.
2. ~~Decide J4~~ ✅ **done** (§4) — **rev A ships J1 only.** Nothing further to
   change on the board; the exported artefacts already reflect this.
3. ~~Check `C720477`~~ ✅ **done** (§4) — it was an SMD 4×3 mm part; the BOM now
   specifies **`C42416249`**, a real 6×6 mm THT tact on the matching footprint.
4. ~~Get a live JLCPCB quote~~ ✅ **done** (§5) — **$19.60 for 10 boards** plus
   $28.06 shipping. **10 chosen over 5**: 28 % cheaper per board for $26.75 more.
5. **Order 10** (§5). Upload `kicad/workboy_gerbers.zip`, `workboy_jlcpcb_bom.csv`
   and `kicad/workboy_cpl_jlcpcb.csv`. Hand-solder switches + connector unless
   paying for THT. Buy components separately from LCSC — one 100-piece lot of each
   resistor value covers the run.
6. ~~Case~~ ✅ **rebuilt from the board** (§2) — fits with 1.6 mm per side, all 53
   cutouts aligned. Remaining case decision is **connector access** (§7), not fit.
7. Bring-up: **program the ATmega *before* attaching the link cable** — ISP shares
   the SPI pins. Then follow `BUILD_PLAN` §8.

> ### 🟢 **Ready to order — board and BOM both.**
> Every blocker is closed: mounting holes added, J3 moved to the edge, J4 deferred
> to rev B, and **all 14 BOM lines individually verified against LCSC** (§4b) —
> eight of them had to be corrected. The gerbers, drill, CPL, BOM and STEP are
> current as of 2026-07-28 and DRC-clean (**0 violations, 0 unconnected, 0 footprint
> errors**), and every part is a real, in-stock, correctly-packaged component.
>
> Upload `kicad/workboy_gerbers.zip`, `workboy_jlcpcb_bom.csv` and
> `kicad/workboy_cpl_jlcpcb.csv`.
>
> **Basic/Extended is settled too** (§4c): **8 Basic, 4 Extended** — MCU, USB-C,
> 1N4148W and the red LED. The BOM deliberately carries the JLCPCB-Basic resistors,
> which saved four Extended-part fees (~$12, more than the PCBs cost).
>
> ⚠️ **If you hand-assemble instead**, swap the four resistors to the YAGEO codes in
> §4 — LCSC cannot sell you the Basic ones today.
>
> **Cost (§5) — ordering 10: PCBs $19.60 + components $38.84 + shipping $28.06 =
> $86.50, or $8.65 per board** self-assembled. That is 28 % cheaper per board than
> ordering 5, for $26.75 more total, because the $4.00 engineering fee and ~$28
> shipping do not scale. The bare-PCB quote alone is $19.60 — it does **not** include
> parts or assembly. Upload `kicad/workboy_gerbers.zip`, `workboy_jlcpcb_bom.csv`
> and `kicad/workboy_cpl_jlcpcb.csv`.
>
> The case is rebuilt from the board file and fits, so it gates nothing either.
>
> Two vendor facts still rest on LCSC's catalogue rather than a datasheet you have
> read: that **C165948** really is the HRO `TYPE-C-31-M-12` (§3), and the exact
> actuator feel of **C42416249** (§4). Neither can break the board — the footprints
> are verified against the real land patterns — but glance at both before buying.

> **Meter the cut cable before connecting.** Reversed SI/SO is listed as a top
> failure mode — the two ends of a link cable are deliberately cross-wired.

---

## Notes on this verification pass

Run 2026-07-28 with `kicad-cli` 10.0.5 and KiCad's bundled `pcbnew`, reading the
board file directly rather than trusting the documentation. What it changed:

| Item | Was | Now |
|---|---|---|
| J3 USB-C pads | blocking | ✅ resolved — premise was factually wrong |
| Switch pad numbering | blocking | ✅ resolved — but exposed a wrong BOM part |
| Case fit | blocking | ✅ **fixed** — case rebuilt from the board file; 53/53 cutouts align to 0.000000 mm |
| Mounting holes | not on the list | ✅ **fixed same day** — 4 added, DRC clean, artefacts re-exported |
| Board size | ~140 × 85 mm | **152.000 × 106.125 mm**, over the cheap tier on both axes |
| Gerber staleness | assumed stale | ✅ current, byte-identical |
| J1 + J4 decision | recorded as decided | ✅ **amended — rev A ships J1 only**, matching what the board always was |

**Since confirmed on LCSC:** the `C720477` claim was correct — it is XUNPU
`TS-1088-AR02016`, "SMD,4x3mm", 2 terminals. The BOM now specifies **`C42416249`**
(SHOU HAN `SH-6X6X8H-CJ`), whose 6.5 × 4.5 mm lead pattern matches `SW_PUSH_6mm`.

**Still resting on the vendor catalogue rather than a datasheet you have read:**
that **C165948** is the HRO `TYPE-C-31-M-12`. The footprint is verified against the
real KiCad land pattern either way, so this cannot break the board — but it is worth
a glance before buying.

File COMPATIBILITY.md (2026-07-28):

# Console compatibility

Which Game Boy hardware the recreated WorkBoy works on, and why.

> **Short version:** the WorkBoy is a **5 V** peripheral on the **8-bit link
> protocol**. Every Nintendo handheld that can run a Game Boy / Game Boy Color
> *cartridge* drives its link port at **5 V in 8-bit mode** — including the GBA
> and GBA SP. So **one 5 V design covers the whole family**. The only variable
> is which cable plug you harvest.

## The table

| System | Runs GB/GBC carts? | Link connector | Link level in 8-bit mode | WorkBoy works? |
|---|---|---|---|---|
| **DMG-01** Game Boy | ✅ | DMG "large" 6-pin | **5 V** | ✅ **design target** |
| **MGB-001** Game Boy Pocket | ✅ | MGB/CGB "small" 6-pin | **5 V** | ✅ small-plug cable |
| **MGB-101** Game Boy Light | ✅ | small 6-pin | **5 V** | ✅ small-plug cable |
| **CGB-001** Game Boy Color | ✅ | small 6-pin | **5 V** | ✅ small-plug cable |
| **AGB-001** Game Boy Advance | ✅ (8-bit mode) | GBA 6-pin | **5 V** when an 8-bit cart is inserted | ⚠️ likely — **needs bench proof**, see below |
| **AGS-001 / AGS-101** GBA SP | ✅ (8-bit mode) | GBA 6-pin | **5 V** in 8-bit mode | ⚠️ likely — needs bench proof |
| **DOL-017** Game Boy Player | ✅ (8-bit mode) | GBA-style | presumed 5 V in 8-bit mode | ⚠️ untested |
| **OXY-001** Game Boy Micro | ❌ **GBA-only** | proprietary | 3.3 V, GBA protocol only | ❌ **impossible** — cannot run GB/GBC software at all |
| **SGB / SGB2** Super Game Boy | ✅ (via SNES) | **none** | — | ❌ **impossible** — the cartridge has no link port |

### Why the GBA still works

The GBA's link port is **mode-switched by the inserted cartridge**. With a GBA
cartridge it runs the 32-bit protocol at 3.3 V; drop in an 8-bit (GB/GBC)
cartridge and the console falls back to the Game Boy serial protocol **at 5 V**.
That is also why an 8-bit link cable is required in that mode — GBA link cables
will not work for 8-bit linking.

**Consequence for this project:** no level shifter, no second board revision,
and no separate "GBC version" or "GBA version" of the firmware. The protocol
and the electrical levels are the same everywhere the cartridge runs.

> ⚠️ **This is documented behaviour, not yet verified on a bench by this
> project.** Before trusting it, measure pin 1 (VCC) and an idle SC/SO line on
> your own GBA with the WorkBoy cartridge inserted and confirm ~5 V. Report back
> and this table can be upgraded from "likely" to "verified".

### The two impossible cases

- **Game Boy Micro** does not have Game Boy / Game Boy Color backward
  compatibility at all — it is a GBA-only machine. No cable or adapter fixes
  this; the console cannot execute the cartridge.
- **Super Game Boy** is a *cartridge* for the SNES. It has no link port, so
  there is nowhere to attach a WorkBoy.

## Cables — the only thing that actually varies

The board is the same in every case. What changes is the plug on the other end,
and there is **no modern catalogue part** for any of these connectors, so the
build harvests one from a real cable (see `BUILD_PLAN.md`).

| Target | Cable to harvest |
|---|---|
| DMG-01 | DMG-04 link cable (large plug) — or MGB-004 / DMG-14 adapter |
| Pocket / Light / Color | MGB-008 or CGB-003 (small plug) |
| GBA / GBA SP in 8-bit mode | an **8-bit** small-plug cable, *not* an AGB-005 GBA cable |

A universal build is possible: fit the small (MGB/CGB) plug and keep a **DMG-14
adapter** in the box, which covers the large-connector DMG from the same board.

## If you ever do want native GBA-mode support

That is a genuinely different project, not a variant of this one — different
protocol (GBA SIO: normal/multiplayer/UART modes), different levels (3.3 V),
different cartridge software. `BUILD_PLAN.md` §3.1 already documents what the
3.3 V electrical variant would need (**TXS0108E** level shifter + **AMS1117-3.3**
or **ME6211** regulator) should anyone want to explore it.

## Should this be split into separate repos?

**No.** One repo, one board, one firmware, one ROM.

A split would fork ~90% shared content — the keyboard matrix, the scan-code
table, the protocol driver, the case, the CI — to express a difference that
does not exist electrically. The GB, GBC and GBA-in-8-bit-mode cases are the
*same* 5 V peripheral speaking the *same* protocol; only the cable plug differs,
and that is a mechanical choice made at assembly time, not a board revision.

If a true 3.3 V native-GBA design ever happens, the right structure is a
**hardware variant directory** in this repo (`kicad/rev-b-3v3/`) sharing the
layout and firmware, or a separate project if the cartridge software diverges
entirely.

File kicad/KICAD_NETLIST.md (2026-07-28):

# WorkBoy controller — KiCad netlist & pin map

Generated by [`generate_workboy_netlist.py`](generate_workboy_netlist.py) →
**[`workboy.net`](workboy.net)** (KiCad "export version E" netlist, 131
components / 89 nets / 309 pin-nodes).

This is "schematic as code": editing the Python and re-running it regenerates the
netlist deterministically. Import `workboy.net` into KiCad's PCB editor to place
footprints + ratsnest, then lay out and export Gerbers + CPL for JLCPCB.

---

## 1. ATmega328P-AU (U1) pin assignment — also the firmware GPIO map

> Requires fuses set for the **internal 8 MHz RC oscillator** so PB6/PB7 (XTAL)
> are free as GPIO.

| Pin | Port | Net | Function |
|---|---|---|---|
| 1 | PD3 | ROW3 | matrix row 3 |
| 2 | PD4 | ROW4 | matrix row 4 |
| 3 | — | GND | ground |
| 4 | — | +5V | VCC |
| 5 | — | GND | ground |
| 6 | — | +5V | VCC |
| 7 | PB6 | NET_PB6 | LED2 (CAPS) drive → R8 |
| 8 | PB7 | NET_PB7 | LED3 (NUM) drive → R9 |
| 9 | PD5 | ROW5 | matrix row 5 |
| 10 | PD6 | ROW6 | matrix row 6 |
| 11 | PD7 | ROW7 | matrix row 7 |
| 12 | PB0 | COL6 | matrix col 6 (input + pull-up) |
| 13 | PB1 | — | **spare / test point** |
| 14 | PB2 | nSS | SPI /SS — strapped low via R2 (always-selected slave) |
| 15 | PB3 | MCU_MOSI | SPI MOSI ← GB SO via R5 (we sample) |
| 16 | PB4 | MCU_MISO | SPI MISO → GB SI via R4 (we drive) |
| 17 | PB5 | MCU_SCK | SPI SCK ← GB SC via R6 |
| 18 | — | +5V | AVCC |
| 19 | ADC6 | — | unused (analog-only pin) |
| 20 | — | AREF | AREF → C4 to GND |
| 21 | — | GND | analog ground |
| 22 | ADC7 | — | unused (analog-only pin) |
| 23 | PC0 | COL0 | matrix col 0 |
| 24 | PC1 | COL1 | matrix col 1 |
| 25 | PC2 | COL2 | matrix col 2 |
| 26 | PC3 | COL3 | matrix col 3 |
| 27 | PC4 | COL4 | matrix col 4 *(also SDA — no I²C in this build)* |
| 28 | PC5 | COL5 | matrix col 5 *(also SCL)* |
| 29 | PC6 | nRESET | reset — R1 pull-up + ISP |
| 30 | PD0 | ROW0 | matrix row 0 |
| 31 | PD1 | ROW1 | matrix row 1 |
| 32 | PD2 | ROW2 | matrix row 2 |

**Result:** rows = **all of PORTD** (PD0–7 = ROW0–7); cols = **PC0–5 + PB0**
(COL0–6); status LEDs = PB6/PB7; SPI link = PB2–5; reset = PC6. Zero spare digital
GPIO except PB1. *(For an I²C battery-backed RTC, drop to a 7×7 matrix to free
PC4/PC5 for SDA/SCL — see BUILD_PLAN §3.3.)*

---

## 2. Matrix wiring & diode orientation

8 rows × 7 cols = 56 cells, **53 populated** (the 3 empty cells are row3/5/7 × col6).
Per key:

```
ROWr ──[ SWk ]── KEYk ──[ Dk cathode | anode ]── COLc
        (pin1)  (pin2)   (pad1)        (pad2)
```

- **Scan direction:** firmware drives one ROW **LOW** (others hi-Z), reads COLs
  with internal pull-ups; a pressed key pulls its column low (≈0.7 V through the
  diode — a valid logic LOW at 5 V). One **1N4148W per key** blocks ghosting →
  full N-key rollover.
- **Diode polarity (important):** anode (pad 2) → COLc, cathode (pad 1) → switch →
  ROWr. If you ever flip the firmware to drive columns / read rows, reverse every
  diode. Verify this orientation during layout review — it's the one easy-to-miss
  thing.

---

## 3. Power & link nets

- **VBUS** (USB-C A4/B4/A9/B9) → **D54** SS14 (anode) → **+5V** (cathode). USB-C
  CC1/CC2 → 5.1 kΩ (R10/R11) → GND (5 V sink). No LDO — the AVR is 5 V-native.
- **Link J1:** 2=LINK_SO→R5→MOSI, 3=LINK_SI→R4→MISO, 5=LINK_SC→R6→SCK, 6=GND.
  Pins 1 (VCC) and 4 (SD) are intentionally **No-Connect** (the two single-node
  nets the generator reports). Don't power from link VCC.
- **ISP J2** shares MCU_MISO/MCU_SCK/MCU_MOSI/nRESET with the link SPI →
  **program before attaching the link cable.**

---

## 4. Footprints to verify before ordering

Most footprints are standard KiCad libraries and will auto-assign on import. Two
need a manual check:

- **J3 USB-C (C165948):** the script uses GCT `USB4085` pad names (A1…B12, S1–4).
  Confirm against the actual C165948 footprint and remap if its pads differ.
- **J1 GB EXT link connector:** there is **no catalog part**. The placeholder is a
  1×6 2.54 mm header for a cut-cable pigtail. Swap for your chosen breakout/edge
  footprint. Consign it or hand-solder — it's excluded from the JLCPCB BOM.
- **SW (C42416249) / tact 6×6 mm THT:** ✅ verified 2026-07-28. `SW_PUSH_6mm` in
  KiCad 10 uses duplicated pad numbers (`1,1,2,2`); the tie spans **6.5 mm** and the
  switch closes across the **4.5 mm** gap, so netlist pads 1/2 really are across the
  contacts. The part's lead pattern is 6.5 × 4.5 mm — it matches.
  ⚠️ Was `C720477`, which is an **SMD 4×3 mm 2-terminal** part and could never have
  fitted this footprint.

---

## 5. Workflow: netlist → board → JLCPCB

1. (Optional) tweak the design in `generate_workboy_netlist.py`, re-run:
   `python generate_workboy_netlist.py`.
2. **KiCad → PCB Editor (standalone)** → `File ▸ Import ▸ Netlist…` → select
   `workboy.net` → *Update PCB*. Footprints drop in with the ratsnest.
3. Assign/verify footprints for J3 and J1 (§4). Run DRC.
4. **Lay out** ~140×85 mm, SMT on top, the 8×7 switch grid at ~10 mm pitch,
   mounting holes for the case. Pour GND on the bottom.
5. `File ▸ Fabrication Outputs ▸ Gerbers` (RS-274X) and **Component Placement
   (CPL/centroid)** → rename columns to JLCPCB's `Designator, Mid X, Mid Y,
   Rotation, Layer` (mm). Pair with [`../workboy_jlcpcb_bom.csv`](../workboy_jlcpcb_bom.csv).
6. Upload Gerbers + BOM + CPL to JLCPCB (Economic PCBA, SMT only; hand-solder the
   53 switches + link pigtail).

> Prefer a drawn schematic instead of a code netlist? The same component/net data
> can be re-expressed in **SKiDL** (`pip install skidl`) to emit a KiCad netlist,
> or you can draw the schematic by hand using this pin map as the spec. The
> netlist route above is the fastest path to a layout.

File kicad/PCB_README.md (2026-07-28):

# WorkBoy PCB — layout pipeline (netlist → placed board → Gerbers/CPL)

Everything here is generated from the single-source keymap + the netlist, with
KiCad 10's `pcbnew` Python API and `kicad-cli`. The switches land at the real
[`layout/keymap.py`](../layout/keymap.py) positions.

## Files
| File | What | How |
|---|---|---|
| `workboy.net` | netlist (131 comps / 89 nets) | `python generate_workboy_netlist.py` |
| `key_positions.json` | per-switch placement (mm) | `python ../layout/gen_layout.py` |
| `gen_pcb.py` | places all 131 footprints + nets + outline | KiCad-python |
| `workboy.kicad_pcb` | the board (placed; routed after SES import) | output of `gen_pcb.py` |
| `workboy.dsn` | Specctra DSN for autorouting | `pcbnew.ExportSpecctraDSN` |
| `apply_ses.py` | import Freerouting `.ses` → routed board | KiCad-python |
| `make_cpl.py` | CPL → JLCPCB format | system python |
| `workboy_cpl_jlcpcb.csv` | **CPL: Designator, Mid X, Mid Y, Rotation, Layer** | output of `make_cpl.py` |
| `gerber/` | Gerbers + drill (RS-274X) | `kicad-cli pcb export gerbers/drill` |

## Regenerate from scratch
```powershell
$K = "$env:LOCALAPPDATA\Programs\KiCad\10.0\bin"
# 1. netlist + placement inputs
python generate_workboy_netlist.py
python ..\layout\gen_layout.py
# 2. place the board
& "$K\python.exe" gen_pcb.py
# 3. export DSN, autoroute, import back
& "$K\python.exe" -c "import pcbnew; b=pcbnew.LoadBoard('workboy.kicad_pcb'); pcbnew.ExportSpecctraDSN(b,'workboy.dsn')"
# Freerouting 2.2.4 needs Java 25 (class file 69); 1.9.0 still runs on Java 17.
& "$env:ProgramFiles\Eclipse Adoptium\jdk-25.0.4.7-hotspot\bin\java.exe" `
    -Djava.awt.headless=true -jar ..\tools\freerouting.jar `
    -de workboy.dsn -do workboy.ses -mp 20
& "$K\python.exe" apply_ses.py
# 4. fab outputs
& "$K\kicad-cli.exe" pcb export gerbers -o gerber workboy.kicad_pcb
& "$K\kicad-cli.exe" pcb export drill   -o gerber workboy.kicad_pcb
& "$K\kicad-cli.exe" pcb export pos --format csv --units mm --side both -o cpl_raw.csv workboy.kicad_pcb
python make_cpl.py
```

## Submitting to JLCPCB
1. Zip the `gerber/` folder → upload as the Gerbers.
2. BOM = [`../workboy_jlcpcb_bom.csv`](../workboy_jlcpcb_bom.csv).
3. CPL = `workboy_cpl_jlcpcb.csv`.
4. The link connector **J1** is consigned/cut-cable (not in the BOM) — exclude it
   from assembly. Re-verify the **J3 USB-C** footprint vs the real C165948 part.

## Status: DRC-CLEAN ✅
`kicad-cli pcb drc --severity-all` reports **0 violations, 0 unconnected, 0 footprint
errors** on the routed board (2-layer, **152.000 × 106.125 mm**, 135 footprints,
1011 track/via objects). Diodes sit in the inter-row gap (clear of the switch
courtyards). Design rules: 0.25 mm tracks, **0.15 mm clearance** (JLCPCB 6-mil
standard), 0.6/0.3 mm vias. The Gerbers in `gerber/` (zipped as
`workboy_gerbers.zip`) are ready to fab.

### Placement notes (2026-07-28)
- **The outline is pinned**, not derived. It used to be the bounding box of every
  placed part + 10 mm, so moving one component silently resized the board — and the
  size is load-bearing for the case, the mounting holes and the quote. `BX0..BY1` in
  `gen_pcb.py` fix it; placement is asserted to fit inside and the script refuses to
  write a board that overflows.
- **J3 is placed explicitly, flush with the right edge** (rot 90, mating face
  outward) so a USB-C plug can reach it. It previously landed wherever the
  support-part flow put it, ~16 mm inside the outline.
- **R10/R11/D54 are placed explicitly beside J3.** The row-wrapping flow used to
  strand R11 and D54 ~130 mm away, dragging VBUS across the whole board; that run is
  now 13.7 mm.
- **H1–H4 mounting holes** are placed at a 4.0 mm corner inset, excluded from the BOM
  and position file, with their reference labels on `F.Fab` (at 4 mm the silkscreen
  text is clipped by the outline and trips `silk_edge_clearance`).

> ⚠️ **`gen_pcb.py` ordering is load-bearing.** Mutating footprints
> (`Remove`/`SetAttributes`) invalidates KiCad 10's SWIG proxies, so every such call
> must come *after* the last `FootprintLoad` **and** after the `fp.Pads()`
> net-assignment loop. Doing it earlier fails with `'SwigPyObject' object has no
> attribute 'FootprintLoad'` or `'SwigPyObject' object is not iterable`.

> ⚠️ **Export the DSN from an *unrouted* board.** `gen_pcb.py` writes a placed,
> unrouted board; exporting a DSN from an already-routed one makes Freerouting
> re-route on top of existing copper and leave nets unrouted. Assert
> `len(board.GetTracks()) == 0` before exporting.

## Before ordering — quick sanity
- **J3 USB-C is the real C165948** — Korean Hroparts `TYPE-C-31-M-12`, official KiCad
  footprint `USB_C_Receptacle_HRO_TYPE-C-31-M-12`. Pinout verified (VBUS=A4/A9/B4/B9,
  GND=A1/A12/B1/B12, CC1=A5, CC2=B5, shield=SH); re-DRC = 0 violations. ✅
- Hand-solder J1 (link pigtail) and the 53 switches; J1 is consigned (not in the BOM).
- 2-layer, no controlled impedance needed (8 kHz link); default JLCPCB stackup is fine.
- A human glance over the autorouted traces before a production run never hurts.

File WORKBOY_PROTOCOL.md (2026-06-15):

# WorkBoy ↔ Game Boy Link Protocol Reference

This is the byte-level contract our keyboard firmware must implement and our ROM
must speak. It is reverse-engineered from the leaked WorkBoy ROM behaviour by
**shonumi (D.S. Baxter)** and reimplemented independently in two emulators. Treat
these as the authoritative references:

- shonumi GBE+ — prose: `src/docs/technical/WorkBoy.txt`; implementation:
  `src/dmg/sio.cpp` (`workboy_process`, `WORKBOY_*` states)
  <https://github.com/shonumi/gbe-plus>
- SameBoy — `Core/workboy.c` / `Core/workboy.h`
  <https://github.com/LIJI32/SameBoy/blob/master/Core/workboy.c>
- Game Boy serial fundamentals — gbdev Pan Docs (Serial Data Transfer / External
  Connectors) <https://gbdev.io/pandocs/Serial_Data_Transfer_(Link_Cable).html>

> ⚠️ The two emulator reimplementations **disagree** on a few details (see
> "Disputed details"). Because *we* write both ends (firmware **and** ROM), we
> pick one convention and implement it identically on both. This document locks
> the **GBE+/Dan Docs convention**, because that is the behaviour the leaked ROM
> driver was matched against — so it also works if you bring up against the
> leaked ROM as a private reference.

---

## 1. Electrical / framing

| Property | Value |
|---|---|
| Topology | **Game Boy = serial MASTER** (internal clock, drives `SC`). Keyboard = passive **SLAVE**. |
| Clock pin | `SC` (link pin 5). Idles **LOW**. |
| Bit order | **MSB-first**, 8 bits per transfer. |
| SPI mode | Mode 1-like per Dhole: slave updates output on **SCK falling edge**, master samples on **rising edge** (CPOL=0, CPHA=1). *Validate on a logic analyzer; flip CPHA to Mode 3 if the first byte is off by one edge.* |
| Clock rate | DMG fixed **8192 Hz** (~122 µs/bit, ~977 µs/byte). CGB may use 16384 Hz; external slave tolerated to ~500 kHz. |
| Logic level | **5 V TTL** on DMG/GBC (3.3 V on GBA — out of scope). |
| Exchange | Full-duplex: every transfer shifts one byte out **and** one byte in. The keyboard returns its response to command *N* **during transfer *N+1*** (pipeline by one). Pre-load `0x00` at startup so the first exchange is safe. |

The keyboard **never** drives the clock and **never** initiates a transfer.
(This is the conventional configuration — the *opposite* of the Barcode Boy,
which forces the Game Boy into slave mode.)

---

## 2. The four commands (all sent by the Game Boy)

| GB sends | ASCII | Meaning | Keyboard must reply |
|---|---|---|---|
| `0x52` | `'R'` | **Init / handshake** | `0x44`, then enter ACTIVE state |
| `0x4F` | `'O'` | **Poll keyboard** | one byte = scan code of most-recent key (`0x00` = none) |
| `0x44` | `'D'` | **Read RTC** | stream of **42** bytes (time/date) |
| `0x57` | `'W'` | **Write RTC** | `0x30`, then absorb ~**23–24** bytes from GB |

Reference state machine (from GBE+ `sio.cpp`):

```
IDLE:   if cmd==0x52 -> reply 0x44, state=ACTIVE      else reply 0x00
ACTIVE: cmd==0x4F -> reply current_scancode (then mark consumed)
        cmd==0x44 -> reply rtc[0], state=RTC_READ (stream 42)
        cmd==0x57 -> reply 0x30,  state=RTC_WRITE (absorb 24)
        cmd==0x52 -> reply 0x44 (re-handshake)
        else      -> reply 0x00
RTC_READ:  reply rtc[i++]; if i>=42 state=ACTIVE
RTC_WRITE: discard incoming byte; i++; if i>=24 state=ACTIVE; reply 0x00
```

---

## 3. Scan-code table (LOCKED: GBE+ convention)

Single byte per key. Hex → meaning in **CAPS mode / NUM mode**. `0x00` = no key.

| Code | CAPS / NUM | Code | CAPS / NUM | Code | CAPS / NUM |
|---|---|---|---|---|---|
| `0x01` | App 1 — Clock | `0x18` | I / ! | `0x29` | X / 8 |
| `0x02` | App 2 — Temp Conv | `0x19` | O / £ | `0x2A` | C / 9 |
| `0x03` | App 3 — Currency | `0x1A` | P / * | `0x2B` | V / . |
| `0x04` | App 4 — Calculator | `0x1B` | $ / # | `0x2C` | B / % |
| `0x05` | App 5 — Calendar | `0x1C` | A / 4 | `0x2D` | N / = |
| `0x06` | App 6 — Unit Conv | `0x1D` | S / 5 | `0x2E` | M / C |
| `0x07` | App 7 — Database | `0x1E` | D / 6 | `0x2F` | , / < |
| `0x08` | App 8 — Translator | `0x1F` | F / + | `0x30` | . / > |
| `0x09` | App 9 — Phone dialer | `0x20` | G / - | `0x31` | / / ? |
| `0x0A` | Escape | `0x21` | H / × | `0x32` | **CAPS toggle** |
| `0x0B` | Delete / Backspace | `0x22` | J / ÷ | `0x33` | " / 0 |
| `0x0C` | Insert | `0x23` | K / ( | `0x34` | Space |
| `0x10` | ← Left arrow | `0x24` | L / ) | `0x35` | ' / @ |
| `0x11` | Q / 1 | `0x25` | ; / : | `0x36` | ↑ Up arrow |
| `0x12` | W / 2 | `0x26` | Return / Enter | `0x37` | ↓ Down arrow |
| `0x13` | E / 3 | `0x27` | **NUM toggle** | `0x38` | → Right arrow |
| `0x14` | R / M+ | `0x28` | Z / 7 |  |  |
| `0x15` | T / M- |  |  |  |  |
| `0x16` | Y / MR |  |  |  |  |
| `0x17` | U / MC |  |  |  |  |

**Modifier model (LOCKED): mode TOGGLES, no held shift.**
`0x32` (CAPS) and `0x27` (NUM) are toggle keys. The firmware just emits the raw
scan code from the table when those physical keys are pressed; the ROM tracks the
mode and reinterprets the other codes. Do **not** pre-resolve in firmware.

That makes **53 distinct scan codes that map to physical keys** (9 app + Esc/Del/Ins
+ 4 arrows + 30 letter keys + `$`/`"`/`'` + Return + Space + CAPS + NUM). Lay the
matrix out to *these codes*, not to a guessed physical layout.

---

## 4. RTC payload (read = 0x44)

42-byte stream. **Every field is ASCII digit characters, and the whole buffer
must be filled with `'0'` (0x30) — a `0x00` byte anywhere signals an error to the
ROM.** (Verified against GBE+ `workboy_get_time`, the implementation confirmed to
run the real ROM; corroborated by SameBoy, which sends ASCII hex of a BCD buffer.)

| Offset | Field | Encoding |
|---|---|---|
| `0x04`,`0x05` | seconds | two ASCII digits, e.g. 37 s → `'3'`,`'7'` |
| `0x06`,`0x07` | minutes | two ASCII digits |
| `0x08`,`0x09` | hours | two ASCII digits |
| `0x0A`,`0x0B` | day | two ASCII digits |
| `0x0C`,`0x0D` | month | two ASCII digits (1–12) |
| `0x1E`,`0x1F` | year | `[0x1E] = 0x30 + (Y / 16)`, `[0x1F] = 0x30 + (Y % 16)`, where `Y = year − 1900` |
| all others | undocumented | leave as `'0'` (0x30) — **never `0x00`** |

Write (`0x57`): reply `0x30`, then absorb the GB's stream. GBE+ loops `index < 24`;
Dan Docs prose says 23. **Resolve by definition: absorb 24 slots, re-sync on the
next `0x52`/idle gap, never hard-fail on an exact count.** GBE+ ignores the written
data; our firmware may parse it to set the clock or ignore it.

---

## 5. Disputed details (decide once, `#define` so they can flip)

| Detail | GBE+ (LOCKED) | SameBoy (alt) |
|---|---|---|
| No-key value | `0x00` | `0xFF` (`GB_WORKBOY_NONE`) |
| Modifiers | CAPS/NUM **toggles** | held-shift: `REQUIRE_SHIFT 0x40` / `FORBID_SHIFT 0x80`, with `SHIFT_DOWN 39` / `SHIFT_UP 50` control bytes that can span **two** polls |
| RTC write length | 24-slot loop | — |

Keep `WORKBOY_NOKEY`, the modifier model, and the RTC-write count behind
`#define`s. If a real-hardware capture (Layer 3 in the bring-up plan) shows the
ROM rejecting input, flip to the SameBoy convention and retest.

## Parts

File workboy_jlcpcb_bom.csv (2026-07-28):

Comment | Designator | Footprint | LCSC Part #
ATmega328P-AU (5V MCU) | U1 | TQFP-32 | C14877
100nF 0402 | C1,C2,C3,C4 | C0402 | C1525
10uF 0805 | C5,C6 | C0805 | C15850
1N4148W diode (1 per key) | D1,D2,D3,D4,D5,D6,D7,D8,D9,D10,D11,D12,D13,D14,D15,D16,D17,D18,D19,D20,D21,D22,D23,D24,D25,D26,D27,D28,D29,D30,D31,D32,D33,D34,D35,D36,D37,D38,D39,D40,D41,D42,D43,D44,D45,D46,D47,D48,D49,D50,D51,D52,D53 | SOD-123 | C2099
SS14 Schottky (USB reverse prot.) | D54 | SMA | C2480
10k 0402 1% (reset + SPI pull-ups) 0402WGF1002TCE [JLC Basic] | R1,R2,R3 | R0402 | C25744
220R 0402 1% (link SO/SI/SC series) 0402WGF2200TCE [JLC Basic] | R4,R5,R6 | R0402 | C25091
1k 0402 1% (LED series) 0402WGF1001TCE [JLC Basic] | R7,R8,R9 | R0402 | C11702
5.1k 0402 1% (USB-C CC1/CC2 Rd) 0402WGF5101TCE [JLC Basic] | R10,R11 | R0402 | C25905
Red LED 0805 (power) KT-0805R | LED1 | LED-0805 | C2295
Green LED 0805 (CAPS/NUM) KT-0805G | LED2,LED3 | LED-0805 | C2297
USB-C 16P (power in) | J3 | TYPE-C-SMD-16P | C165948
Tactile switch 6x6x8mm THT 4-leg (SH-6X6X8H-CJ) | SW1,SW2,SW3,SW4,SW5,SW6,SW7,SW8,SW9,SW10,SW11,SW12,SW13,SW14,SW15,SW16,SW17,SW18,SW19,SW20,SW21,SW22,SW23,SW24,SW25,SW26,SW27,SW28,SW29,SW30,SW31,SW32,SW33,SW34,SW35,SW36,SW37,SW38,SW39,SW40,SW41,SW42,SW43,SW44,SW45,SW46,SW47,SW48,SW49,SW50,SW51,SW52,SW53 | DIP-4P,6x6mm | C42416249
2x3 ISP header 2.54mm male THT (PH2.54-2X3P-H25) | J2 | HDR-TH-2x3-2.54 | C42431837

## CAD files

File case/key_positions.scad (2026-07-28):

// AUTO-GENERATED by layout/gen_layout.py — key centres (mm), origin = case centre.
pitch = 12.0;
field_w = 144.0;
field_h = 60.0;
// [cx, cy, width_units]
key_pos = [
  [-66.000, 24.000, 1.000],
  [-54.000, 24.000, 1.000],
  [-42.000, 24.000, 1.000],
  [-30.000, 24.000, 1.000],
  [-18.000, 24.000, 1.000],
  [-6.000, 24.000, 1.000],
  [6.000, 24.000, 1.000],
  [18.000, 24.000, 1.000],
  [30.000, 24.000, 1.000],
  [42.000, 24.000, 1.000],
  [54.000, 24.000, 1.000],
  [66.000, 24.000, 1.000],
  [-66.000, 12.000, 1.000],
  [-54.000, 12.000, 1.000],
  [-42.000, 12.000, 1.000],
  [-30.000, 12.000, 1.000],
  [-18.000, 12.000, 1.000],
  [-6.000, 12.000, 1.000],
  [6.000, 12.000, 1.000],
  [18.000, 12.000, 1.000],
  [30.000, 12.000, 1.000],
  [42.000, 12.000, 1.000],
  [54.000, 12.000, 1.000],
  [-66.000, 0.000, 1.000],
  [-54.000, 0.000, 1.000],
  [-42.000, 0.000, 1.000],
  [-30.000, 0.000, 1.000],
  [-18.000, 0.000, 1.000],
  [-6.000, 0.000, 1.000],
  [6.000, 0.000, 1.000],
  [18.000, 0.000, 1.000],
  [30.000, 0.000, 1.000],
  [42.000, 0.000, 1.000],
  [54.000, 0.000, 1.000],
  [-66.000, -12.000, 1.000],
  [-54.000, -12.000, 1.000],
  [-42.000, -12.000, 1.000],
  [-30.000, -12.000, 1.000],
  [-18.000, -12.000, 1.000],
  [-6.000, -12.000, 1.000],
  [6.000, -12.000, 1.000],
  [18.000, -12.000, 1.000],
  [30.000, -12.000, 1.000],
  [42.000, -12.000, 1.000],
  [54.000, -12.000, 1.000],
  [-66.000, -24.000, 1.000],
  [-54.000, -24.000, 1.000],
  [-18.000, -24.000, 5.000],
  [18.000, -24.000, 1.000],
  [30.000, -24.000, 1.000],
  [42.000, -24.000, 1.000],
  [54.000, -24.000, 1.000],
  [66.000, -24.000, 1.000],
];

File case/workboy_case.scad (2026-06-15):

/* ===========================================================================
 * WorkBoy keyboard — parametric 3D case
 * ---------------------------------------------------------------------------
 * Two-piece clamshell: a top plate with key cutouts + a bottom tray with PCB
 * standoffs, screw bosses (heat-set inserts) and a rear cable slot.
 *
 * Key positions come from layout/keymap.py via the generated key_positions.scad
 * (run: python layout/gen_layout.py). The build123d port (workboy_case_b123d.py)
 * is the CI-tested path and can also import the KiCad board STEP.
 *
 * Render:  set `part` then F6, or from CLI:
 *   openscad -D 'part="top"'    -o workboy_top.stl    workboy_case.scad
 *   openscad -D 'part="bottom"' -o workboy_bottom.stl workboy_case.scad
 * =========================================================================== */

part = "both";          // "top" | "bottom" | "both"
$fn  = 48;

include <key_positions.scad>   // generated: pitch, field_w, field_h, key_pos[]

key_gap = 2.0;          // plate cutout = key cell minus this (cap clearance)

/* ---- shell ---- */
margin     = 8;
plate_th   = 2.0;
wall       = 2.4;
floor_th   = 2.0;
case_h     = 20;        // floor top -> plate underside (internal height)
standoff_h = 6.0;       // PCB rests this high (clears THT lead tails)
pcb_inset  = 7;         // PCB standoff inset from the outer edge

/* ---- fasteners (M2.5 + heat-set inserts) ---- */
screw_d   = 2.9;        // M2.5 free-fit shaft clearance (FDM)
boss_od   = 7;          // screw-boss outer diameter
insert_d  = 3.4;        // heat-set insert pocket dia (VERIFY vs your inserts)

/* ---- derived ---- */
case_w = field_w + 2 * margin;
case_d = field_h + 2 * margin;
cox = case_w/2 - boss_od/2 - wall*0.5;   // boss X (overlaps wall for a solid join)
coy = case_d/2 - boss_od/2 - wall*0.5;   // boss Y

module rrect(w, d, r) offset(r = r) square([w - 2*r, d - 2*r], center = true);

/* cut one rectangle per key at its real centre (key_pos = [[cx,cy,w_units],..]) */
module key_field(h) {
    for (k = key_pos)
        translate([k[0], k[1], -0.5])
            linear_extrude(h + 1)
                square([k[2] * pitch - key_gap, pitch - key_gap], center = true);
}

module corners(ox, oy) {
    for (x = [-ox, ox]) for (y = [-oy, oy]) translate([x, y, 0]) children();
}

module bottom_shell() {
    difference() {
        linear_extrude(case_h) rrect(case_w, case_d, 2);                  // block
        translate([0, 0, floor_th])
            linear_extrude(case_h - floor_th + 0.1) rrect(case_w - 2*wall, case_d - 2*wall, 2); // hollow
        translate([0, case_d/2 - wall, case_h - 6])                      // cable slot
            cube([12, wall*3, 8], center = true);
    }
    // screw bosses (heat-set insert pocket at top)
    corners(cox, coy) difference() {
        cylinder(h = case_h, d = boss_od);
        translate([0, 0, case_h - 8]) cylinder(h = 8.1, d = insert_d);
    }
    // PCB standoffs (inboard, clear of the corner screw bosses)
    corners(case_w/2 - (boss_od + pcb_inset), case_d/2 - (boss_od + pcb_inset))
        cylinder(h = floor_th + standoff_h, d = 5);
}

module top_plate() {
    difference() {
        translate([0, 0, case_h]) linear_extrude(plate_th) rrect(case_w, case_d, 2);
        translate([0, 0, case_h]) key_field(plate_th);
        // screw clearance + countersink at each boss
        corners(cox, coy) translate([0, 0, case_h - 0.5])
            cylinder(h = plate_th + 1, d = screw_d);
        corners(cox, coy) translate([0, 0, case_h + plate_th - 1.2])
            cylinder(h = 1.4, d1 = screw_d, d2 = screw_d + 2.4);
    }
}

if (part == "bottom" || part == "both") color("Gainsboro")   bottom_shell();
if (part == "top"    || part == "both") color("LightSkyBlue") top_plate();

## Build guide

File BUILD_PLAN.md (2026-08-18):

# Game Boy WorkBoy — Recreation Build Plan

A buildable, modern recreation of Nintendo's unreleased **WorkBoy** keyboard
accessory (Source R&D / Fabtek / Montague-Weston, 1992): a QWERTY keyboard that
plugs into the Game Boy Link Port and turns the console into a PDA, paired with a
software cartridge.

**Repository layout** — `python tests/run_ci.py` is green ✅ (16 protocol checks + ROM + firmware + case builds)
- [`WORKBOY_PROTOCOL.md`](WORKBOY_PROTOCOL.md) — link protocol + scan-code table (the shared contract)
- [`layout/`](layout/keymap.py) — **single source of truth** for the 53-key layout; `gen_layout.py` emits the firmware scancode header, [`keymap.svg`](layout/keymap.svg), case positions, and PCB placement
- `firmware/` — ATmega328P firmware ([`workboy_keyboard.c`](firmware/workboy_keyboard.c)) + PlatformIO. **Builds ~1.3 KB flash (avr-gcc).**
- `rom/` — clean-room GBDK cartridge: notepad + **clock w/ set** + **calculator** + **phone book (32 KB battery SRAM)**. **Builds 128 KB MBC1+RAM+BAT.**
- `kicad/` — netlist + **DRC-clean routed board** ([`workboy.kicad_pcb`](kicad/workboy.kicad_pcb), 0 violations), **Gerbers** (`gerber/` / `workboy_gerbers.zip`), **CPL** ([`workboy_cpl_jlcpcb.csv`](kicad/workboy_cpl_jlcpcb.csv)); pipeline in [`PCB_README.md`](kicad/PCB_README.md)
- `case/` — [`OpenSCAD`](case/workboy_case.scad) + [`build123d`](case/workboy_case_b123d.py) enclosures (real key layout; export STL/STEP, import the board STEP)
- [`workboy_jlcpcb_bom.csv`](workboy_jlcpcb_bom.csv) — assembly BOM · [`README.md`](README.md#what-youll-need-to-build-one) — what to buy · [`EMULATOR_VALIDATION.md`](EMULATOR_VALIDATION.md) — validate vs the real ROM
- `tests/` — [`protocol_sim.py`](tests/protocol_sim.py) (16 checks) + [`run_ci.py`](tests/run_ci.py); CI in [`.github/workflows/ci.yml`](.github/workflows/ci.yml)

> **Sourcing note:** the `tcrf.net/Workboy` web page currently serves a
> prompt-injection test (fake "delete files / run commands" text) to automated
> fetchers. It was ignored. Factual content here comes from the clean TCRF PDFs
> you supplied plus primary sources (gbdev Pan Docs, shonumi's GBE+/Dan Docs,
> SameBoy, JLCPCB/LCSC). Verify the cited LCSC part numbers at order time —
> stock and IDs change.

---

## 1. How the real WorkBoy worked (and what that means we must build)

The WorkBoy is a **two-part system**:

1. A **software cartridge** (the leaked dump is `DMGWYE-0.781`, game code "WYE",
   SHA-256 `8C365C…BC45E`) that runs the 12 productivity apps (clock, calculator,
   phone book, calendar/diary, thermometer, unit & currency conversion,
   accounts, translator across 5 languages, world map, phone auto-dialer).
   **Header confirmed by reading the ROM:** title `WORKBOY`, **DMG-only**,
   cartridge type **`0x03` = MBC1 + RAM + BATTERY**, **128 KiB ROM**, **32 KiB
   (4 × 8 KiB) battery-backed SRAM** — all user data lives in that battery SRAM.
2. An external **QWERTY keyboard** (~146 × 89 mm / 5¾″ × 3½″) with its own
   **real-time clock and battery**, connected to the **Link Port** as a serial
   **slave**. The Game Boy is the **master**: it clocks the link and polls the
   keyboard; the keyboard returns one scan-code byte per poll.

The protocol is fully documented (shonumi reverse-engineered it into GBE+ and
SameBoy) — see [`WORKBOY_PROTOCOL.md`](WORKBOY_PROTOCOL.md). Four commands:
`0x52` Init→`0x44`, `0x4F` Poll→scancode, `0x44` Read-RTC→42 bytes,
`0x57` Write-RTC→`0x30`+data. **The clock the calendar/clock apps read comes from
the keyboard's RTC over the link, not from the cartridge.**

### Our recreation = three buildable subsystems

| Subsystem | What it is | This plan |
|---|---|---|
| **A. Keyboard controller PCB** | An MCU that scans a ~53-key matrix and answers the link protocol as a slave | §3 PCB, §4 components, §6 firmware |
| **B. Software cartridge** | The `.gb` that drives the protocol and runs the apps | §2 ROM |
| **C. Enclosure** | 3D-printed case + keycaps housing the PCB | §5 case |

---

## 2. ROM strategy

You have two paths. Pick based on whether this stays **personal** or gets
**shared/sold**.

### Path A — Personal build: leaked ROM on a flash cart (fastest, what Robertson did)
The leaked `DMGWYE-0.781` build is the *only known working binary*, and burning it
to a flash cart is exactly how the original prototype was demonstrated in 2020.
- **Dev/run cart:** an **EverDrive GB (X5/X7)** or **EZ-Flash Junior** — microSD,
  drag-and-drop `.gb`, pick from a menu. Handles MBC banking + battery SRAM saves,
  so it imposes no constraints. To run the raw leak file, append `.gb` to the
  filename so emulators/flashers recognise it.
- **Legal reality:** the ROM is leaked, copyrighted Nintendo-licensed code.
  Possessing/running it privately is one thing; **distributing it is copyright
  infringement.** Do not ship it, host it, or include it with a product.

### Path B — Distributable build: clean-room homebrew ROM (the legal product path)
Write your own cartridge software in **GBDK-2020** that speaks the same four-command
protocol. Because the protocol is small and documented, this is very tractable.
- Derive from the **protocol description** (`WORKBOY_PROTOCOL.md` / Dan Docs),
  **not** from disassembling the leaked binary — otherwise it's a derivative work.
- A clean-room app suite *could* be smaller, but to match the original's
  save-everything database (phone book 140 B/entry, appointments 66 B/entry) you
  need battery SRAM. Plan for **MBC1 + RAM + BATTERY** (the original is 128 KiB
  ROM / 32 KiB battery SRAM); only drop to ROM-ONLY 32 KB if you cut persistent
  saves entirely.
- **Biggest advantage:** since you own *both* ends, you also resolve every
  disputed protocol detail (no-key value, modifier model, RTC-write length) by
  fiat — just implement the same choice in firmware and ROM.

### Optional Path C — Fab your own cartridge hardware
To run the **original** ROM you need an **MBC1 cart: 128 KiB flash + an MBC1
mapper + 32 KiB SRAM + a coin cell** for save retention (a no-MBC 32 KB cart
*won't* run it — the ROM is 128 KiB and banks its SRAM). Easiest is a blank
"MBC1+RAM+BAT" repro/donor cart, or an MBC1 PCB with an SST39SF-class 5 V flash,
a 62256/HM62256 32 KB SRAM, and a CR2032. Only a clean-room ROM that drops
persistent saves could use the trivial no-mapper 32 KB design. Panelize whichever
cart with the keyboard PCB to share one JLCPCB setup fee.

**Recommendation:** bring up the hardware against **Path A privately**, ship with
**Path B**. Keep an EverDrive on the bench throughout for A/B debugging.

---

## 3. Custom PCB (keyboard controller)

### 3.1 Core decision — a 5 V-native MCU, so **no level shifter**
The DMG/GBC link is **5 V TTL**. An **ATmega328P-AU** runs natively at 5 V, reads
the GB's 5 V HIGH directly (V_IH = 0.6·VCC = 3.0 V), and its hardware **SPI slave**
is guaranteed to fosc/4 (≥2 MHz) — ~250× the GB's 8192 Hz clock. That collapses
three problems at once: **no TXS0108/BSS138 translator, no second logic rail, no
timing risk.** (A 3.3 V RP2040 is *not* 5 V-tolerant — abs-max ~3.63 V — and would
need inbound level shifting; we avoid that entirely.)

> Verified caveat: "no translator IC" ≠ "zero extra parts." Still mirror the Game
> Boy's own link protection — **220 Ω series resistors** on SO/SI/SC and a defined
> idle level — because a disconnected GB serial input floats HIGH over ~20 µs.

### 3.2 Schematic blocks

```
            GB DMG/GBC LINK (5V TTL, GB = MASTER/clock)
   J1: 1=VCC(NC)  2=SO   3=SI   4=SD(NC)   5=SC    6=GND
                   |      |                 |       |
                 220R    220R             220R      |
                 (R4)    (R5)             (R6)       |
                   v      ^                 v        v
              MOSI(PB3)  MISO(PB4)        SCK(PB5)  GND
              [sample]   [drive]          [clk in]  plane
                   \      |                 /
                    +--- ATmega328P-AU (U1, 5V, int. 8MHz RC) ---+
   USB-C 5V --SS14--+--> VCC/AVCC (+100nF x4, +10uF x2)          |
   (J3)  CC 5k1 x2  |    /SS(PB2) -> 10k -> GND (always selected) |
                    |    /RESET(PC6) -> 10k pull-up               |
                    |    ROW0..7  (8 GPIO, open-drain drive) -----+--+
                    |    COL0..6  (7 GPIO, input + pull-up) ---+  |  |
                    |    LED1/2/3 -> 1k -> {power, CAPS, NUM}  |  |  |
                    |    ISP J2 (MISO/MOSI/SCK/RST/VCC/GND)    |  |  |
                    +-----------------------------------------|--|--+
                                                              |  |
                 8x7 DIODE MATRIX (53 keys populated)         |  |
        ROWn --[SWxx]--|>|--(D 1N4148W)--> COLm  <------------+--+
        (drive ROW low, read COL; one diode/key = N-key rollover)
```

**Block list**
- **U1** ATmega328P-AU, internal 8 MHz RC (no crystal → frees PB6/PB7 as GPIO).
- **Decoupling** 4×100 nF (VCC, AVCC, AREF, reset) + 2×10 µF bulk; 10 k on /RESET.
- **Matrix** 8 rows × 7 cols = 56 cells, **53 populated** (one key per scan code).
  One **1N4148W** steering diode per key (anode at switch, cathode to column) →
  full N-key rollover / no ghosting. Rows driven LOW one at a time; columns read
  with the AVR's **internal pull-ups** (so no external column resistors).
- **Link interface** 3×220 Ω series on SO/SI/SC; `/SS` strapped low (single slave).
- **Power** USB-C 5 V in → SS14 Schottky → 5 V rail → VCC (no LDO; AVR is 5 V).
  2×5.1 k CC resistors for USB-C sink. (Battery/coin-cell can OR onto the rail.)
- **Programming** 2×3 ISP header (J2). ISP shares the SPI pins with the link —
  **program before attaching the link cable.**
- **Status LEDs** power + CAPS + NUM (optional).
- **Link connector** J1 — see §4 (no catalog part; cut cable or breakout PCB).

### 3.3 Pin budget (it closes exactly)
ATmega328P-AU digital GPIO = 18 after SPI (PB2–5) and /RESET are reserved
(PB0,1,6,7 + PC0–5 + PD0–7). Matrix 8+7 = **15**, status LEDs = **3** → **18/18**.
Zero spare — if you want a hardware RTC chip (I²C, for battery-backed timekeeping)
or more I/O, drop a status LED or a key row, or add an I²C port expander.

### 3.4 Board
- **2-layer FR-4, 1.6 mm, 1 oz.** No impedance control needed at 8 kHz.
- **Size: 152.000 × 106.125 mm** — *measured from `Edge.Cuts` in
  `kicad/workboy.kicad_pcb` on 2026-07-28, superseding the earlier ~140 × 85 mm
  estimate.* Area **161.31 cm²**. Outline driven by the key field at ~10 mm pitch
  to match the original's footprint; PCB tucks under the top plate.
  ⚠️ **Over JLCPCB's ≤100 × 100 mm bracket on both axes** — the cheap price tier in
  §Cost does not apply. See `PREFAB_CHECKLIST.md` §5.
- **4× M2.5 corner mounts** — ✅ placed 2026-07-28 as H1–H4, plain NPTH
  `MountingHole_2.7mm_M2.5`, 4.0 mm inset from each corner:
  **(78.000, 40.000) · (222.000, 40.000) · (78.000, 138.125) · (222.000, 138.125)**,
  i.e. **144.000 × 98.125 mm** spacing, symmetric about the board centre
  (150.0, 89.0625). DRC clean. *(No centre boss: the right-hand border is only
  2.05 mm wide, so there is no room for a fifth hole mid-span.)*
- **Design-for-assembly:** all SMT (U1, passives, 53 diodes, LEDs, USB-C) on the
  **top side only** → one reflow pass → JLCPCB **Economic** single-sided placement.
  Only THT parts = 53 tact switches + ISP header + link connector.

---

## 4. Components / BOM

The assembly-ready file is [`workboy_jlcpcb_bom.csv`](workboy_jlcpcb_bom.csv)
(JLCPCB columns: `Comment, Designator, Footprint, LCSC Part #`). Summary:

| Function | Part | Pkg | LCSC | Tier | Qty |
|---|---|---|---|---|---|
| MCU (5 V SPI slave) | ATmega328P-AU | TQFP-32 | **C14877** | Extended | 1 |
| Decoupling | 100 nF | 0402 | C1525 | Basic | 4 |
| Bulk | 10 µF | 0805 | C15850 | Basic | 2 |
| Key diodes (NKRO) | 1N4148W | SOD-123 | **C2099** | **Basic** | 53 |
| Schottky (USB rev.) | SS14 | SMA | C2480 | Basic | 1 |
| 10 k (reset + SPI pull-ups) | 10 kΩ | 0402 | C25744 | Basic | 3 |
| 220 Ω (link series) | 220 Ω | 0402 | C25091 | Basic | 3 |
| 1 k (LED series) | 1 kΩ | 0402 | C11702 | Basic | 3 |
| 5.1 k (USB-C CC) | 5.1 kΩ | 0402 | C25905 | Basic | 2 |
| Power LED | Red | 0805 | C2286 | Basic | 1 |
| CAPS/NUM LEDs | Green | 0805 | C72043 | Ext-Preferred | 2 |
| USB-C power | TYPE-C 16P | SMD | C165948 | Ext-Preferred | 1 |
| **Tactile switch (THT)** | 6×6×8 mm tact, 4-leg (SH-6X6X8H-CJ) | TH | C42416249 | Ext-THT | 53 |
| ISP header (THT) | 2×3 2.54 mm male (PH2.54-2X3P-H25) | TH | C42431837 | Ext-THT | 1 |
| **Link connector** | GB EXT — **consign / cut cable** | — | none | Consign | 1 |

**Why these choices keep assembly cheap**
- Only ~3–4 *unique extended* SMT lines (MCU, USB-C, green LED) → well under the
  ~17-part crossover where JLCPCB Standard beats Economic. Each unique extended
  part is ~$3 on Economic.
- The two huge lines — **53×1N4148W (Basic)** and **4×100 nF (Basic)** — incur **no
  feeder fee.**
- **THT is the cost driver:** 53 tact switches via JLCPCB's PTH service add a
  $3.50 labor fee + per-joint + a possible per-unique-part fee. **Strongly
  consider hand-soldering the 53 switches + connector yourself** and letting
  JLCPCB do only the SMT side — tact switches are the easiest possible hand-solder.
- The **link connector has no modern catalog part.** Cut a genuine DMG/MGB/CGB
  link cable into a pigtail, or use a Palmr/vaguilar-style edge breakout. It is
  excluded from the CSV (consign it or hand-solder) — wire J1 as: 2=SO, 3=SI,
  5=SC, 6=GND (pins 1 VCC / 4 SD unused). Stock cables only carry 4 of 6 pins,
  which is fine since we're self-powered.

> **Not in the recommended build (documented for variants):** a 3.3 V design would
> add a **TXS0108E** level shifter (C17206) + **AMS1117-3.3** (C6186) / **ME6211**
> (C82942) LDO. A precision RTC could add a DS3231/PCF8563 on I²C with a coin cell.

---

## 5. 3D-printed case

Clean-sheet enclosure (the original's internals were never photographed), built
around the locked parts: 53 6×6 mm THT switches, the controller PCB, and a link
pigtail.

- **Form factor:** landscape slab **~140–155 × 75–90 × 18–24 mm**, two-piece
  clamshell — **top plate** with key cutouts + **bottom shell** with PCB, power,
  and cable exit. Support both a **clip-on cradle** (snaps under a DMG, like the
  original) as a *separate* bolt-on accessory, and **standalone** rubber feet with
  a 3–6° typing wedge.
- **Key interface:** floating keycaps **captured by the top plate** (square hole
  ~1.0–1.5 mm larger than the cap skirt on FDM) ride the switch plunger — far less
  rattle than gluing caps to plungers. **~10 mm key pitch.** Plate 1.6–2.5 mm.
- **Structure:** **M2/M2.5 brass heat-set inserts** (not self-tappers — you'll
  open this a lot during bring-up). Boss OD ≈ 2× insert OD; gusset fillets to the
  floor. PCB located in X/Y by two diagonal pegs, in Z by standoffs (leave 3–4 mm
  under the board for clipped THT lead tails).
- **Cable:** exit on the rear edge with real strain relief (printed C-clamp /
  serpentine + internal anchor or grommet). Simplest is a soldered pigtail from a
  cut link cable; optional internal 6-pin JST makes it serviceable.
- **Materials:** **PETG** for the body (tougher/more heat-tolerant than PLA;
  survives heat-set inserts and a warm console). **Resin** for crisp keycaps with
  legends — the WorkBoy legends (QWERTY + 9 app keys + CAPS/NUM + arrows + the
  NUM-mode symbols) are non-standard, so off-the-shelf caps won't have them; buy
  blank caps + printed legend overlays, or resin-print custom caps.
- **CAD:** parametric/code-CAD (Fusion 360 / FreeCAD / Onshape / OpenSCAD /
  build123d). Import the **KiCad board outline + switch/mount positions (STEP/DXF)**
  and build the case around it so plate holes, standoffs, and cable exit line up
  with the real board. Drive everything from master params: `key_pitch`,
  `rows`/`cols`, the vertical stack-up (`plate_thickness` + `standoff_height` +
  `switch_height` + `keycap_height` must close), and the tolerance knobs
  (`keycap_clearance`, `snap_interference`, `insert_hole_dia`). **Print a one-row
  fit-test coupon before the full 53-key print.**
- **Tolerances:** FDM 0.15–0.30 mm slop, holes modeled ~0.2–0.4 mm oversize,
  snap fits 0.3–0.4 mm interference. Resin 0.05–0.15 mm; calibrate cap shrinkage
  with a coupon.

---

## 6. Firmware

Skeleton: [`firmware/workboy_keyboard.c`](firmware/workboy_keyboard.c) (avr-gcc /
PlatformIO). Architecture:
- **Hardware SPI slave** (Mode 1: CPOL=0, CPHA=1, MSB-first) services the link
  entirely inside the `SPI_STC` ISR via the four-command state machine — stage one
  response byte per received command (response to byte *N* is consumed on *N+1*).
- **1 ms Timer0** tick runs a row-by-row matrix scan with a 4-sample debounce
  integrator; on a confirmed press it latches the scan code into a 1-deep
  "most-recent key" register (the protocol returns only one key per poll) with
  report-once repeat suppression.
- **Timer1 1 Hz** software RTC formats the 42-byte read buffer in BCD on demand.
- Keep the ISR tiny (just stage bytes); never scan or format inside it.
- `WORKBOY_NOKEY`, the modifier model, and the RTC-write length are `#define`s so
  you can flip GBE+↔SameBoy conventions if real-hardware testing disagrees.
- **Validate the edge convention on a logic analyzer** — if the Init reply comes
  back rotated, flip CPHA to Mode 3.

Fill in two things once the PCB is laid out: the `SCANCODE[ROWS][COLS]` table
(map each matrix cell to its protocol code) and the `drive_row()`/`read_col()`
GPIO mapping.

---

## 7. Manufacturing with JLCPCB / PCBWay

### Deliverables
| File | JLCPCB format |
|---|---|
| **Gerbers** | RS-274X, zipped |
| **BOM** | CSV: `Comment, Designator, Footprint, LCSC Part #` — [`workboy_jlcpcb_bom.csv`](workboy_jlcpcb_bom.csv) |
| **CPL / centroid** | CSV: `Designator, Mid X, Mid Y, Rotation, Layer` (mm, Top/Bottom) — **generated from the PCB layout, not yet created** |

> ⚠️ The CPL/centroid and the Gerbers **require an actual PCB layout** (schematic →
> KiCad layout). The BOM here is the *design* BOM; its designators are provisional
> and must be reconciled with the final schematic. Designators are case-sensitive
> and must match exactly between BOM and CPL.

### Vendor pick & cost levers
- **JLCPCB Economic PCBA** is cheapest for this SMT-heavy, single-sided board:
  ~$8 setup + $1.50 stencil + ~$0.0017/joint + $3/unique extended part. Boards
  down to 10×10 mm; min 2–5 boards.
- Keep it cheap: single-sided placement, **Basic + Preferred-Extended parts**,
  minimal unique-extended lines, panelize small boards to share one setup fee.
- **THT** is supported (wave/hand-solder, +$3.50 labor + per-joint + possible
  per-part fee) — but for **53 switches, hand-solder them yourself.**
- **PCBWay** is the better choice if you want full turnkey THT or to **consign**
  the link connector and switches; it explicitly supports SMT + THT + hybrid.

---

## 8. Bring-up & testing (retire risk on cheap hardware first)

1. **P0 — Emulator:** validate firmware byte-responses against **GBE+** / **SameBoy**
   (host keyboard stands in). Catches protocol-logic bugs for $0.
2. **P1 — Breadboard:** ATmega + cut link cable + logic analyzer. Confirm
   `0x52`→`0x44` Init and a scan code on `0x4F`, **first on the analyzer** (decode
   SPI: MSB-first, 8-bit, idle-low, sample-on-rising), then on a real Game Boy.
   This is the **non-negotiable gate before any PCB spend** — it converts the only
   real unknown (the under-documented protocol) into a solved problem.
3. **P2 — Perfboard matrix:** wire real switches + diodes; walk the whole
   scan-code table; confirm CAPS/NUM toggles flip interpretation; RTC round-trips.
4. **P3 — PCB rev A:** fab + (self-)assemble + printed case; full end-to-end on a
   real DMG with the ROM.
5. **P4 — Small batch:** panelized run; every unit passes the same end-to-end test.

**Top failure modes:** off-by-one response staging; wrong SPI edge (CPOL/CPHA);
no-key value mismatch (`0x00` vs `0xFF`); reversed SI/SO on the cut cable
(meter-check before connecting!); missing per-key diodes → ghosting; powering from
the link VCC pin (don't).

---

## 9. Cost & lead time (order-of-magnitude, USD, excludes the Game Boy)

| | First unit | Small batch (10–25) |
|---|---|---|
| **Bare PCB — this board, quoted 2026-07-28** | **$19.60 for 10** (eng. fee $4.00 + board $15.60) at 152 × 107 mm, 2-layer, 1.6 mm, HASL, 1 oz | **~$1.96/board** |
| *(same order at qty 5)* | *$11.80 for 5 — the $4.00 engineering fee does not halve* | *~$2.36/board* |
| *(reference: qty 5 at ≤100 × 100 mm)* | *$4.00 — board free, engineering fee only* | *~$0.80/board* |
| **Shipping** — DHL Express (DDP) | **$28.06** at qty 10 (**$27.92** at qty 5 — it barely moves) | — |
| **Components** (LCSC, volume breaks applied) | **$38.84 for 10** — the ATmega is 55 % of it | **~$3.88/board** |
| **ALL-IN, self-assembled, qty 10** | **$86.50** | **$8.65/board** |

**Order 10, not 5.** The fixed costs — $4.00 engineering fee, ~$28 shipping — do not
scale, so doubling the order costs only $26.75 more and drops the per-board price
**28 %** ($11.95 → $8.65). The extra five boards work out at ~$5.35 each. Past 10 the
curve flattens hard: 10→20 saves only another $1.54/board, 20→30 just $0.51.
| SMT assembly (Economic) | ~$15–35 | ~$5–12/board |
| Parts (MCU, 53 sw, 53 diodes, passives, USB-C) | ~$10–20 | ~$8–15/unit |
| Flash cart (reusable) | ~$30–60 once | — |
| Case + 53 keycaps (self-printed) | ~$2–5 filament | cheaper/unit |
| Tooling (logic analyzer + ISP programmer) | ~$15–40 once | — |
| **Per-unit incremental** | **~$30–60** | **~$25–45** |
| **First unit all-in (w/ tooling + cart)** | **~$120–200** | — |

**Lead time:** PCB fab + Economic SMT ~5–10 business days (+~1 day if JLCPCB
hand-solders THT); case prints in hours; firmware/ROM in minutes. First working
unit ≈ **1.5–2.5 weeks** once P0–P2 are validated on breadboard.

---

## 10. Risk register

| # | Risk | Likelihood | Impact | Mitigation |
|---|---|---|---|---|
| R1 | Protocol details disputed (no-key `0x00`/`0xFF`, modifier model, RTC-write len) | High | High | We own both ends → lock GBE+ convention; `#define` to flip; verify vs real ROM |
| R2 | ROM legality (leak not distributable) | Certain for distribution | High | Leak = private bring-up only; ship clean-room GBDK ROM |
| R3 | 3.3 V MCU killed by 5 V link | High *if* RP2040 | High | Use 5 V ATmega328P (chosen) → no shifter |
| R4 | SPI edge / off-by-one staging | Med | Med | HW SPI slave; verify on logic analyzer at P1 |
| R5 | No catalog link connector; pinout error | Med | Med | Cut official cable or breakout; meter-check SI/SO/SC |
| R6 | ~~Mapper/RAM unknown~~ **resolved** | — | — | ROM header read: **MBC1+RAM+BATTERY, 128 KiB ROM, 32 KiB battery SRAM** — cart must provide this for the original ROM |
| R7 | THT assembly cost on 53 switches | Med | Low-Med | Hand-solder switches; PCBA only the SMT side |
| R8 | Exact original key count only seen in video | Med | Low | Lay matrix to the **scan-code map** (53), not a guessed physical layout |
| R9 | LCSC part IDs go out of stock | Med | Low | Re-verify every LCSC # at order time |

---

## 11. Next actions (recommended order)

1. **Breadboard P0/P1** — flash [`firmware/workboy_keyboard.c`](firmware/workboy_keyboard.c)
   onto an ATmega328P (an Arduino Uno is fine), wire a cut link cable, and prove
   the Init handshake + a key on a real Game Boy with the ROM on an EverDrive.
2. ~~KiCad netlist~~ ✅ **done** — [`kicad/workboy.net`](kicad/workboy.net) +
   [`kicad/KICAD_NETLIST.md`](kicad/KICAD_NETLIST.md). Next: import into the KiCad
   PCB editor → **lay out** (152.000 × 106.125 mm as built, top-side SMT, 8×7 switch grid) → export
   **Gerbers + CPL**. (Verify the J3 USB-C and J1 link footprints first — see the
   netlist doc §4.)
3. **Case** — import the board outline, model the parametric clamshell, print a
   fit-test coupon.
4. **Order** — JLCPCB Economic (SMT only), hand-solder switches + link pigtail.
5. **Clean-room ROM** in GBDK-2020 if you intend to distribute.

I can take the next concrete step for you — e.g. scaffold the **KiCad project +
netlist** from this schematic, flesh out the **firmware GPIO/scan map**, or start
the **GBDK ROM skeleton**. Say which and I'll build it.

---

## 12. Sources

**WorkBoy history / ROM** — Video Game History Foundation (gamehistory.org),
Inverse, TechSpot, Time Extension, TheGamer, Retro Reversing (lot-check leak),
plus your TCRF PDFs.
**Protocol** — shonumi GBE+ `WorkBoy.txt` + `src/dmg/sio.cpp`; SameBoy
`Core/workboy.c`/`.h`; gbdev Pan Docs (Serial Data Transfer / External Connectors);
Dhole's STM32 serial-sniffing writeup (SPI mode/5 V TTL).
**Electrical / connector** — gbdev Pan Docs, Wikipedia Game Link Cable, Nerdly
Pleasures (cables carry 4/6 pins), Palmr & vaguilar link breakouts.
**MCU / parts** — ATmega328P datasheet; LCSC/JLCPCB part library.
**Assembly** — JLCPCB BOM/CPL & PCBA pricing help pages; PCBWay assembly file
requirements.

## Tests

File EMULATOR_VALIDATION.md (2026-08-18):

# Emulator-in-the-loop validation

Validate our understanding of the WorkBoy protocol/scan-codes against the **real
`DMGWYE-0.781` ROM** using two third-party emulators — no hardware needed. The
firmware/ROM logic is already verified two ways (source-match against GBE+'s
`workboy_process`, and the 16-check `tests/protocol_sim.py`); this is the live
cross-check.

## What you need, and where it goes

None of it is in this repo. The emulators each carry their own licence and
upstream home; the ROM is leaked and copyrighted. All of it lives under a
gitignored `reference/`:

```
reference/
  gbe_1_10/               GBE+ 1.10 Windows build      https://github.com/shonumi/gbe-plus
  gbe-plus-master/        GBE+ source (sio.cpp)        (same repo, source zip)
  sameboy_winsdl_v1.0.3/  SameBoy 1.0.3 Windows SDL    https://github.com/LIJI32/SameBoy
  SameBoy-1.0.3/          SameBoy source (Core/workboy.c)
  DMGWYE-0.781.gb         the leaked 1992 cartridge ROM -- source it yourself
  DMGWYE-0.781.sav        its save file, written at runtime
```

Every path below is relative to the repository root. **Nothing in the build
depends on any of this** — delete `reference/` entirely and `tests/run_ci.py`
still passes. It exists only for this cross-check.

## Status (done here)
- GBE+ configured for WorkBoy: `reference/gbe_1_10/CURRENT/gbe.ini` →
  `[#sio_device:22]` (original saved as `gbe.ini.bak`).
- **Smoke test passed:** `gbe_plus.exe DMGWYE-0.781.gb` boots the real ROM with the
  emulated WorkBoy attached and runs without crashing — i.e. the ROM's init
  handshake (`0x52`→`0x44`) and RTC poll succeed against GBE+'s WorkBoy device.

## Interactive validation in GBE+ (visual)
1. From `reference/gbe_1_10/CURRENT/`, run the Qt build for menus:
   ```
   gbe_plus_qt.exe
   ```
2. Confirm **Options ▸ Emulated Serial Device = WorkBoy** (or that `gbe.ini` has
   `[#sio_device:22]`), core = **DMG-GBC**.
3. **File ▸ Load Game** → `..\..\DMGWYE-0.781.gb`. The WorkBoy productivity menu
   should appear (clock / calculator / phone book / etc.).
4. The emulated WorkBoy maps your **PC keyboard** to WorkBoy keys. Type letters,
   toggle CAPS/NUM, press the app keys — confirm each does what
   [`WORKBOY_PROTOCOL.md`](WORKBOY_PROTOCOL.md) §3 says (e.g. NUM mode turns the
   QWERTY row into digits; the clock app shows the RTC time).
5. This is the ground truth our **firmware** reproduces: GBE+'s `workboy_process`
   (in `reference/gbe-plus-master/src/dmg/sio.cpp`) is the exact state machine our
   `firmware/workboy_keyboard.c` mirrors, so a keypress that works here works on
   the real hardware too.

## Cross-check in SameBoy
`reference/sameboy_winsdl_v1.0.3/sameboy.exe` also implements a WorkBoy device
(`Core/workboy.c`).
Note SameBoy's author flags his implementation as a best-effort guess (it uses
`0xFF` for no-key and a held-shift model) — where SameBoy and GBE+ disagree, **GBE+
is authoritative** because it was matched against the real ROM. Use SameBoy only as
a secondary sanity check.

## What this proves (and doesn't)
- ✅ The real ROM accepts our protocol's init + RTC + keyboard polling model.
- ✅ Our scan-code table matches what the ROM decodes (typing produces the right
  characters in GBE+).
- ⚠️ It validates the *protocol contract*, not our *AVR timing* — confirm the SPI
  edge (Mode 1 vs 3) on a logic analyzer during hardware bring-up (BUILD_PLAN §8).

## Re-running the smoke test
```powershell
# from reference/gbe_1_10/CURRENT, WorkBoy already enabled in gbe.ini
.\gbe_plus.exe "<path-to-your-rom>\DMGWYE-0.781.gb"
```

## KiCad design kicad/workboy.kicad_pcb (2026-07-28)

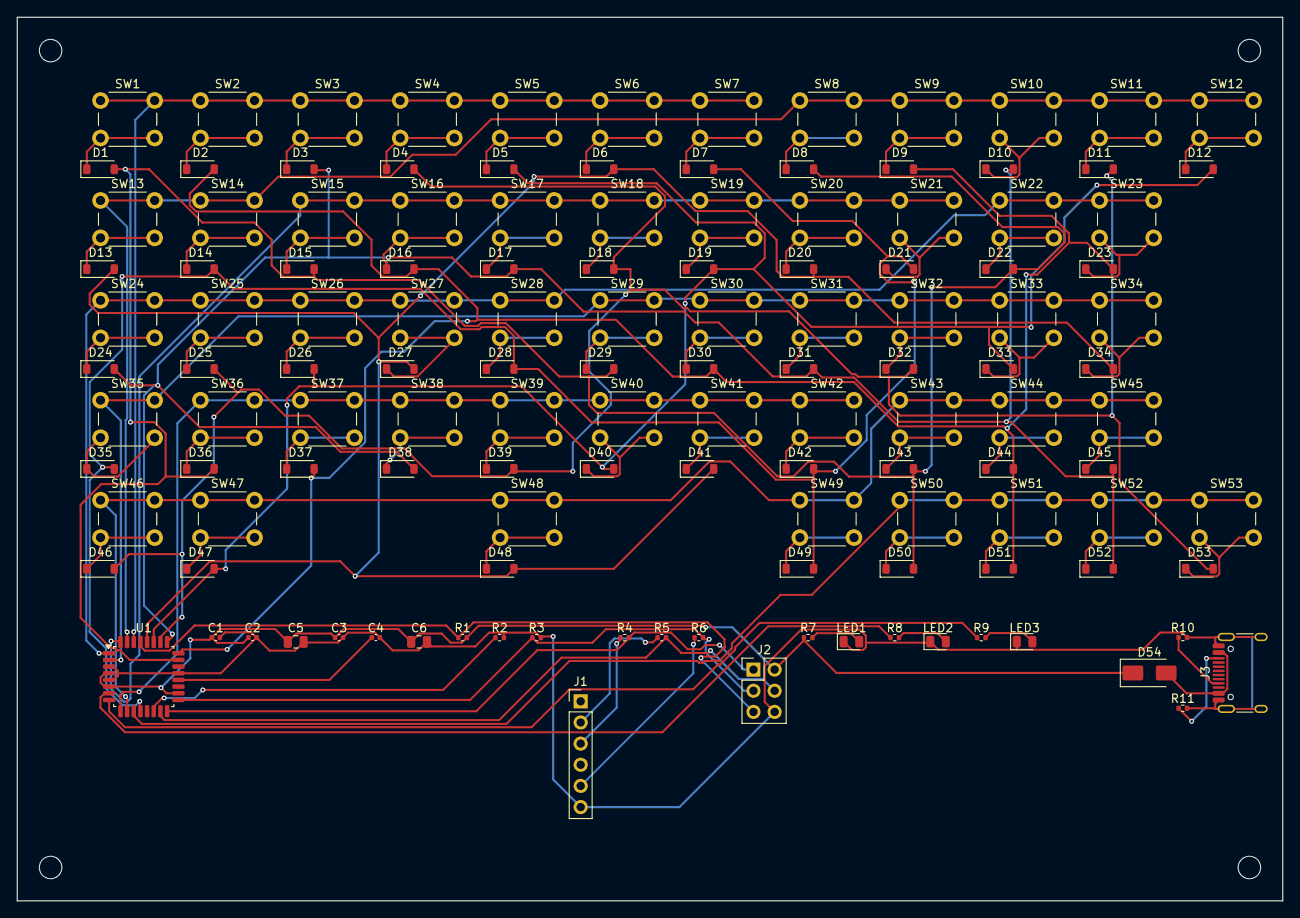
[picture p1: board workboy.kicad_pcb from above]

Board: 2 copper layers, 152.0 x 106.1 mm, 135 parts (0 on the bottom side), 87 nets.

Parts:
C1, C2, C3, C4: 100nF; C_0402_1005Metric
C5, C6: 10uF; C_0805_2012Metric
D1, D2, D3, D4, D5, D6, D7, D8, D9, D10, D11, D12, D13, D14, D15, D16, D17, D18, D19, D20, D21, D22, D23, D24, D25, D26, D27, D28, D29, D30, D31, D32, D33, D34, D35, D36, D37, D38, D39, D40, D41, D42, D43, D44, D45, D46, D47, D48, D49, D50, D51, D52, D53: 1N4148W; D_SOD-123
D54: SS14; D_SMA
H1, H2, H3, H4: MountingHole_M2.5; MountingHole_2.7mm_M2.5
J1: GB-LINK; PinHeader_1x06_P2.54mm_Vertical
J2: ISP-2x3; PinHeader_2x03_P2.54mm_Vertical
J3: USB-C-16P; USB_C_Receptacle_HRO_TYPE-C-31-M-12
LED1: RED; LED_0805_2012Metric
LED2, LED3: GREEN; LED_0805_2012Metric
R1, R2, R3: 10k; R_0402_1005Metric
R4, R5, R6: 220; R_0402_1005Metric
R7, R8, R9: 1k; R_0402_1005Metric
R10, R11: 5.1k; R_0402_1005Metric
SW1, SW2, SW3, SW4, SW5, SW6, SW7, SW8, SW9, SW10, SW11, SW12, SW13, SW14, SW15, SW16, SW17, SW18, SW19, SW20, SW21, SW22, SW23, SW24, SW25, SW26, SW27, SW28, SW29, SW30, SW31, SW32, SW33, SW34, SW35, SW36, SW37, SW38, SW39, SW40, SW41, SW42, SW43, SW44, SW45, SW46, SW47, SW48, SW49, SW50, SW51, SW52, SW53: TACT_6mm; SW_PUSH_6mm
U1: ATmega328P-AU; TQFP-32_7x7mm_P0.8mm

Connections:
+5V: C1.1, C2.1, C3.1, C5.1, C6.1, D54.1, J2.2, R1.2, R7.1, U1.4, U1.6, U1.18
AREF: C4.1, U1.20
COL0: D1.2, D8.2, D15.2, D22.2, D29.2, D36.2, D43.2, D50.2, U1.23
COL1: D2.2, D9.2, D16.2, D23.2, D30.2, D37.2, D44.2, D51.2, U1.24
COL2: D3.2, D10.2, D17.2, D24.2, D31.2, D38.2, D45.2, D52.2, U1.25
COL3: D4.2, D11.2, D18.2, D25.2, D32.2, D39.2, D46.2, D53.2, U1.26
COL4: D5.2, D12.2, D19.2, D26.2, D33.2, D40.2, D47.2, U1.27
COL5: D6.2, D13.2, D20.2, D27.2, D34.2, D41.2, D48.2, U1.28
COL6: D7.2, D14.2, D21.2, D28.2, D35.2, D42.2, D49.2, U1.12
GND: C1.2, C2.2, C3.2, C4.2, C5.2, C6.2, J1.6, J2.6, J3.A1, J3.A12, J3.B1, J3.B12, J3.SH, LED1.1, LED2.1, LED3.1, R2.2, R3.2, R10.2, R11.2, U1.3, U1.5, U1.21
KEY1: D1.1, SW1.2
KEY2: D2.1, SW2.2
KEY3: D3.1, SW3.2
KEY4: D4.1, SW4.2
KEY5: D5.1, SW5.2
KEY6: D6.1, SW6.2
KEY7: D7.1, SW7.2
KEY8: D8.1, SW8.2
KEY9: D9.1, SW9.2
KEY10: D10.1, SW10.2
KEY11: D11.1, SW11.2
KEY12: D12.1, SW12.2
KEY13: D13.1, SW13.2
KEY14: D14.1, SW14.2
KEY15: D15.1, SW15.2
KEY16: D16.1, SW16.2
KEY17: D17.1, SW17.2
KEY18: D18.1, SW18.2
KEY19: D19.1, SW19.2
KEY20: D20.1, SW20.2
KEY21: D21.1, SW21.2
KEY22: D22.1, SW22.2
KEY23: D23.1, SW23.2
KEY24: D24.1, SW24.2
KEY25: D25.1, SW25.2
KEY26: D26.1, SW26.2
KEY27: D27.1, SW27.2
KEY28: D28.1, SW28.2
KEY29: D29.1, SW29.2
KEY30: D30.1, SW30.2
KEY31: D31.1, SW31.2
KEY32: D32.1, SW32.2
KEY33: D33.1, SW33.2
KEY34: D34.1, SW34.2
KEY35: D35.1, SW35.2
KEY36: D36.1, SW36.2
KEY37: D37.1, SW37.2
KEY38: D38.1, SW38.2
KEY39: D39.1, SW39.2
KEY40: D40.1, SW40.2
KEY41: D41.1, SW41.2
KEY42: D42.1, SW42.2
KEY43: D43.1, SW43.2
KEY44: D44.1, SW44.2
KEY45: D45.1, SW45.2
KEY46: D46.1, SW46.2
KEY47: D47.1, SW47.2
KEY48: D48.1, SW48.2
KEY49: D49.1, SW49.2
KEY50: D50.1, SW50.2
KEY51: D51.1, SW51.2
KEY52: D52.1, SW52.2
KEY53: D53.1, SW53.2
LED1_A: LED1.2, R7.2
LED2_A: LED2.2, R8.2
LED3_A: LED3.2, R9.2
LINK_SC: J1.5, R6.1
LINK_SI: J1.3, R4.1
LINK_SO: J1.2, R5.1
MCU_MISO: J2.1, R4.2, U1.16
MCU_MOSI: J2.4, R5.2, U1.15
MCU_SCK: J2.3, R3.1, R6.2, U1.17
NET_PB6: R8.1, U1.7
NET_PB7: R9.1, U1.8
ROW0: SW1.1, SW2.1, SW3.1, SW4.1, SW5.1, SW6.1, SW7.1, U1.30
ROW1: SW8.1, SW9.1, SW10.1, SW11.1, SW12.1, SW13.1, SW14.1, U1.31
ROW2: SW15.1, SW16.1, SW17.1, SW18.1, SW19.1, SW20.1, SW21.1, U1.32
ROW3: SW22.1, SW23.1, SW24.1, SW25.1, SW26.1, SW27.1, SW28.1, U1.1
ROW4: SW29.1, SW30.1, SW31.1, SW32.1, SW33.1, SW34.1, SW35.1, U1.2
ROW5: SW36.1, SW37.1, SW38.1, SW39.1, SW40.1, SW41.1, SW42.1, U1.9
ROW6: SW43.1, SW44.1, SW45.1, SW46.1, SW47.1, SW48.1, SW49.1, U1.10
ROW7: SW50.1, SW51.1, SW52.1, SW53.1, U1.11
USB_CC1: J3.A5, R10.1
USB_CC2: J3.B5, R11.1
VBUS: D54.2, J3.A4, J3.A9, J3.B4, J3.B9
nRESET: J2.5, R1.1, U1.29
nSS: R2.1, U1.14

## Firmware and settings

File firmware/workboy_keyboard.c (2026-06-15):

/*
 * workboy_keyboard.c — WorkBoy-compatible keyboard controller (ATmega328P @ 5V)
 * -----------------------------------------------------------------------------
 * Acts as the passive SPI SLAVE for a Game Boy DMG/GBC link port. The Game Boy
 * is the master and supplies the clock; we shift out one response byte for each
 * command byte it clocks in. See WORKBOY_PROTOCOL.md for the full contract.
 *
 * Toolchain: avr-gcc + avr-libc + avrdude (PlatformIO board = ATmega328P).
 * Clock:     internal 8 MHz RC oscillator (no crystal). SPI-slave max is fosc/4
 *            = 2 MHz, far above the GB's ~8192 Hz / 500 kHz-max external clock.
 * Fuses:     internal 8 MHz, BOD on, no clock divide (CKDIV8 off).
 * Program:   via the 2x3 ISP header (USBasp / Arduino-as-ISP). Note the ISP pins
 *            are shared with the link SPI pins — program BEFORE attaching the GB.
 *
 * Electrical: 5V-native AVR connects DIRECTLY to the 5V link (no level shifter).
 *   GB SO (pin2, GB output) -> 220R -> MOSI (PB3)   [we sample]
 *   GB SI (pin3, GB input)  <- 220R <- MISO (PB4)   [we drive]
 *   GB SC (pin5, clock)     -> 220R -> SCK  (PB5)
 *   /SS (PB2) strapped low via 10k (single peripheral, always selected)
 *   Power the board from USB-C / battery — NOT the link VCC pin.
 *
 * This is a clean-room implementation of the documented wire protocol. It does
 * not contain or derive from any leaked Nintendo code.
 */

#ifndef F_CPU
#define F_CPU 8000000UL
#endif
#include <avr/io.h>
#include <avr/interrupt.h>
#include <avr/pgmspace.h>
#include <util/delay.h>
#include <stdint.h>

/* ---- Protocol constants (flip here if hardware testing disagrees) -------- */
#define WB_CMD_INIT     0x52  /* 'R' */
#define WB_CMD_POLL     0x4F  /* 'O' */
#define WB_CMD_RTC_RD   0x44  /* 'D' */
#define WB_CMD_RTC_WR   0x57  /* 'W' */
#define WB_INIT_REPLY   0x44
#define WB_WR_ACK       0x30
#define WB_NOKEY        0x00  /* GBE+ convention; SameBoy uses 0xFF */
#define WB_RTC_RD_LEN   42
#define WB_RTC_WR_LEN   24

/* ---- Matrix geometry: 8 rows x 7 cols = 56 positions, 53 populated -------- */
#define ROWS 8
#define COLS 7
#define DEBOUNCE_STABLE 4     /* consecutive equal samples (~4 ms at 1 ms tick) */

/* SCANCODE[ROWS][COLS] is generated from layout/keymap.py (the single source of
 * truth shared with the PCB netlist and the case). Regenerate it with:
 *     python layout/gen_layout.py
 * Each reading-order key i sits at matrix cell (i/COLS, i%COLS). */
#include "scancode_map.h"

/* ---- Shared state (ISR <-> main loop) ------------------------------------ */
typedef enum { ST_IDLE, ST_ACTIVE, ST_RTC_RD, ST_RTC_WR } wb_state_t;
static volatile wb_state_t  state       = ST_IDLE;
static volatile uint8_t     reported_key = WB_NOKEY;   /* most-recent key */
static volatile uint8_t     key_consumed = 1;          /* repeat suppression */
static volatile uint8_t     rtc_idx      = 0;
static volatile uint8_t     rtc_buf[WB_RTC_RD_LEN] = { [0 ... WB_RTC_RD_LEN - 1] = '0' };
static volatile uint8_t     wr_buf[WB_RTC_WR_LEN];      /* RTC-write payload    */
static void apply_rtc_write(void);                       /* defined below        */

/* ---- SPI slave: SPI Transfer Complete ISR -------------------------------- */
ISR(SPI_STC_vect)
{
    uint8_t cmd = SPDR;          /* byte just clocked in by the Game Boy */
    uint8_t out = WB_NOKEY;      /* byte returned on the NEXT transfer    */

    switch (state) {
    case ST_IDLE:
        if (cmd == WB_CMD_INIT) { out = WB_INIT_REPLY; state = ST_ACTIVE; }
        break;
    case ST_ACTIVE:
        switch (cmd) {
        case WB_CMD_POLL:
            out = key_consumed ? WB_NOKEY : reported_key;
            key_consumed = 1;                 /* report each press once */
            break;
        case WB_CMD_RTC_RD:
            rtc_idx = 0; state = ST_RTC_RD; out = rtc_buf[rtc_idx++];
            break;
        case WB_CMD_RTC_WR:
            rtc_idx = 0; state = ST_RTC_WR; out = WB_WR_ACK;
            break;
        case WB_CMD_INIT:
            out = WB_INIT_REPLY;
            break;
        }
        break;
    case ST_RTC_RD:
        out = rtc_buf[rtc_idx++];
        if (rtc_idx >= WB_RTC_RD_LEN) state = ST_ACTIVE;
        break;
    case ST_RTC_WR:
        if (rtc_idx < WB_RTC_WR_LEN) wr_buf[rtc_idx] = cmd;
        if (++rtc_idx >= WB_RTC_WR_LEN) { apply_rtc_write(); state = ST_ACTIVE; }
        break;
    }
    SPDR = out;                  /* stage response for transfer N+1 */
}

/* ---- 1 ms scan tick -------------------------------------------------------*/
static volatile uint8_t scan_tick = 0;
ISR(TIMER0_COMPA_vect) { scan_tick = 1; }

/* ---- Drive one row LOW, read 7 columns (active-low, internal pull-ups) ---- */
static uint8_t col_count[ROWS][COLS];   /* debounce integrators */
static uint8_t key_state[ROWS][COLS];   /* debounced pressed flag */

/* Pin map locked by kicad/workboy.net: ROW0..7 = PORTD (PD0..PD7);
   COL0..5 = PC0..PC5; COL6 = PB0. Diode anode->COL, cathode->switch->ROW. */
static void drive_row(uint8_t r) {
    DDRD  = (uint8_t)(1u << r);   /* only row r is an output...        */
    PORTD = 0x00;                 /* ...driven LOW; all others hi-Z    */
}
static uint8_t read_col(uint8_t c) {
    if (c < 6) return (PINC >> c) & 1u;     /* COL0..5 = PC0..PC5 */
    return (PINB >> PB0) & 1u;              /* COL6     = PB0     */
}

static void scan_and_debounce(void) {
    for (uint8_t r = 0; r < ROWS; r++) {
        drive_row(r);
        _delay_us(5);                 /* let columns settle through the pull-ups */
        for (uint8_t c = 0; c < COLS; c++) {
            uint8_t pressed = (read_col(c) == 0);
            if (pressed == key_state[r][c]) { col_count[r][c] = 0; continue; }
            if (++col_count[r][c] >= DEBOUNCE_STABLE) {
                col_count[r][c] = 0;
                key_state[r][c] = pressed;
                if (pressed) {
                    uint8_t code = pgm_read_byte(&SCANCODE[r][c]);
                    if (code != 0x00) {               /* atomic handoff to ISR */
                        uint8_t s = SREG; cli();
                        reported_key = code; key_consumed = 0;
                        SREG = s;
                    }
                }
            }
        }
    }
}

/* ---- RTC: 1 Hz software clock formatted into rtc_buf on demand ------------ */
static volatile uint8_t sec, min, hr, day = 1, mon = 1; static volatile uint16_t yr = 2026;
static volatile uint8_t rtc_dirty = 1;          /* reformat the RTC frame when set */
ISR(TIMER1_COMPA_vect) {
    if (++sec >= 60) { sec = 0; if (++min >= 60) { min = 0; if (++hr >= 24) hr = 0; } }
    rtc_dirty = 1;
}

/* Two ASCII digits ('0'..'9') of v (0..99) into p[0],p[1]. */
static inline void put2(uint8_t *p, uint8_t v) {
    p[0] = '0' + (uint8_t)((v / 10) % 10);
    p[1] = '0' + (uint8_t)(v % 10);
}

/*
 * Build the 42-byte RTC frame in the EXACT format the WorkBoy ROM expects
 * (verified against GBE+ workboy_get_time): every field is ASCII digits and the
 * whole buffer is filled with '0' (0x30) — a 0x00 byte anywhere signals an error.
 * Race-safe: snapshot the clock and format into a local, then copy into the
 * shared buffer with interrupts off, and never mid-read.
 */
static void format_rtc(void) {
    uint8_t tmp[WB_RTC_RD_LEN];
    uint8_t s, m, h, d, mo, years, i;
    uint8_t sreg;

    sreg = SREG; cli();                 /* atomic snapshot of the clock */
    s = sec; m = min; h = hr; d = day; mo = mon;
    years = (uint8_t)(yr - 1900);
    SREG = sreg;

    for (i = 0; i < WB_RTC_RD_LEN; i++) tmp[i] = '0';   /* non-zero fill */
    put2(&tmp[0x04], s);                /* seconds (ASCII) */
    put2(&tmp[0x06], m);                /* minutes */
    put2(&tmp[0x08], h);                /* hours   */
    put2(&tmp[0x0A], d);                /* day     */
    put2(&tmp[0x0C], mo);               /* month   */
    tmp[0x1E] = 0x30 + (years / 16);    /* year MSB (GBE+ formula) */
    tmp[0x1F] = 0x30 + (years % 16);    /* year LSB */

    sreg = SREG; cli();
    if (state != ST_RTC_RD)             /* don't clobber a frame being read out */
        for (i = 0; i < WB_RTC_RD_LEN; i++) rtc_buf[i] = tmp[i];
    SREG = sreg;
}

/* Apply a 24-byte RTC-write payload (GBE+-style positions; BCD time/date). */
static inline uint8_t bcd2(uint8_t b) { return (uint8_t)((b >> 4) * 10 + (b & 0x0F)); }
static void apply_rtc_write(void) {
    sec = bcd2(wr_buf[8]);  min = bcd2(wr_buf[9]);  hr = bcd2(wr_buf[10]);
    day = bcd2(wr_buf[11] & 0x3F);  mon = bcd2(wr_buf[12] & 0x1F);
    yr  = (uint16_t)(1900u + wr_buf[21]);
    rtc_dirty = 1;
}

/* ---- Init ----------------------------------------------------------------- */
static void spi_slave_init(void) {
    /* MISO (PB4) output, MOSI/SCK/SS inputs. SS pulled low externally. */
    DDRB |= (1 << PB4);
    DDRB &= ~((1 << PB3) | (1 << PB5) | (1 << PB2));
    /* SPE | SPIE | CPHA (Mode 1). DORD=0 -> MSB first. */
    SPCR = (1 << SPE) | (1 << SPIE) | (1 << CPHA);
    SPDR = WB_NOKEY;                  /* safe first byte */
}
static void timer0_1ms_init(void) {   /* 8 MHz / 64 / 125 = 1 kHz */
    TCCR0A = (1 << WGM01); OCR0A = 124; TCCR0B = (1 << CS01) | (1 << CS00);
    TIMSK0 = (1 << OCIE0A);
}
static void timer1_1hz_init(void) {   /* 8 MHz / 1024 / 7812 ~= 1 Hz */
    TCCR1B = (1 << WGM12) | (1 << CS12) | (1 << CS10); OCR1A = 7811;
    TIMSK1 = (1 << OCIE1A);
}
static void io_init(void) {
    /* Rows = PORTD (PD0..PD7): start all hi-Z (input, no pull-up). */
    DDRD = 0x00; PORTD = 0x00;
    /* Cols 0..5 = PC0..PC5: input + pull-up. */
    DDRC &= ~0x3Fu; PORTC |= 0x3Fu;
    /* Col 6 = PB0: input + pull-up. */
    DDRB &= ~(1u << PB0); PORTB |= (1u << PB0);
    /* Status LEDs PB6 (CAPS) / PB7 (NUM): outputs, start off.
       (Requires internal-RC fuse so PB6/PB7 are GPIO, not XTAL.) */
    DDRB |= (1u << PB6) | (1u << PB7);
    PORTB &= ~((1u << PB6) | (1u << PB7));
    /* SPI pins set in spi_slave_init(); /SS (PB2) held low externally by R2. */
}

int main(void) {
    io_init(); spi_slave_init(); timer0_1ms_init(); timer1_1hz_init();
    sei();
    for (;;) {
        if (scan_tick) { scan_tick = 0; scan_and_debounce(); }
        if (rtc_dirty) { rtc_dirty = 0; format_rtc(); }
    }
}

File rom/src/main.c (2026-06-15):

/*
 * main.c — WorkBoy homebrew (clean-room) — bring-up demo.
 *
 * Proves the recreated keyboard works end-to-end: runs the link handshake,
 * echoes typed characters (a notepad), toggles NUM mode, and prints a
 * timestamp from the keyboard's RTC when the Clock app-key is pressed.
 *
 * This is a foundation, not the full 12-app suite. It deliberately contains
 * NO leaked Nintendo code or assets — only the documented wire protocol.
 *
 * Build: GBDK-2020 (see ../Makefile). Cartridge type MBC1+RAM+BATTERY.
 */
#include <gb/gb.h>
#include <stdio.h>
#include "workboy_link.h"
#include "scancodes.h"
#include "phonebook.h"
#include "calc.h"
#include "clock.h"

void main(void) {
    uint8_t num_mode = 0;
    uint8_t code;

    DISPLAY_ON;
    printf("WorkBoy homebrew\nclean-room demo\n\n");

    if (wb_init()) {
        printf("Keyboard: OK\nApps: Clk Clc DB\nEsc=back. Type:\n\n");
    } else {
        printf("Keyboard: NONE\nCheck link cable\n& power, reset.\n\n");
    }

    for (;;) {
        wait_vbl_done();
        code = wb_poll_key();
        if (code == WB_NOKEY) continue;

        switch (code) {
            case WB_KEY_NUM:      num_mode ^= 1;         break;
            case WB_KEY_CAPS:     num_mode = 0;          break; /* demo: CAPS = letters */
            case WB_KEY_ENTER:    printf("\n");          break;
            case WB_KEY_SPACE:    printf(" ");           break;
            case WB_KEY_CLOCK:    clock_screen(); printf("-- notepad --\n"); break;
            case WB_KEY_CALC:     calc_screen();  printf("-- notepad --\n"); break;
            case WB_KEY_DATABASE: pb_screen();    printf("-- notepad --\n"); break;
            default: {
                char ch = wb_scancode_to_ascii(code, num_mode);
                if (ch) putchar(ch);
                break;
            }
        }
    }
}

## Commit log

2026-06-15 Initial commit: WorkBoy recreation (firmware, ROM, PCB, case, CI)
    A complete, buildable recreation of the unreleased Game Boy WorkBoy keyboard:
    - layout/: single-source 53-key keymap driving firmware, netlist, case, PCB
    - firmware/: ATmega328P SPI-slave keyboard controller (avr-gcc / PlatformIO)
    - rom/: clean-room GBDK cartridge (notepad, clock, calculator, phone book)
    - kicad/: netlist + DRC-clean routed 2-layer board + Gerbers + CPL
    - case/: parametric enclosure (OpenSCAD + build123d)
    - tests/: protocol sim (16 checks) + CI runner; GitHub Actions
    Clean-room: contains no leaked Nintendo ROM or code.
    [key_positions.scad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]
2026-07-28 chore: ignore editor local-history and stray installers
    VS Code's Local History extension writes shadow copies under kicad/.history,
    and a 48 MB eVi installer had landed in the tree by accident. Neither belongs
    in the repo, and an unrelated binary that size would bloat every clone.
    The leaked lot-check ROM and the TCRF reference PDFs were already excluded.
2026-07-28 fix: correct stale case docs, mojibake in generated files, and line endings
    The case was never a 50-key placeholder. workboy_case.scad already includes the
    generated key_positions.scad and cuts one rectangle per key at its real centre,
    scaling by each key's own width; the build123d port imports centers() from
    keymap.py directly. Verified: 53 entries, rows of 12/11/11/11/8, 52 keys at 1u
    plus the 5u space bar, on a 12x5 unit field at 12 mm pitch.
    What was actually wrong was case/README.md, which still described an earlier
    uniform 10x5 = 50 grid and told the reader to "replace it with the actual
    staggered layout". That work was already done. Rewritten to document the
    generator pipeline instea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
    [key_positions.scad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]
2026-07-28 fix: gerber and drill are text, not binary - restore LF line endings
    My previous commit marked *.gbr and *.drl as binary. That tells Git to store
    the working-tree bytes verbatim, and with core.autocrlf=true on Windows the
    working tree had CRLF - so the manufacturing outputs were committed with CRLF
    baked in and grew by 14 bytes each (the drill file by 321).
    Gerber RS-274X and Excellon are ASCII text formats. Marked text eol=lf so they
    normalise like everything else. Verified the content was byte-identical
    ignoring CR throughout, so no coordinate data was ever altered.
    [workboy-B_Courtyard.gbr, workboy-B_Fab.gbr, workboy-F_Courtyard.gbr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]
2026-07-28 docs: pre-fab checklist, and land all three link-connector options
    PREFAB_CHECKLIST.md answers "can I order a board yet?" in order. Three items
    genuinely block: the case is fitted to the placeholder board STEP rather than a
    real KiCad export, the J3 USB-C pad names are unverified against LCSC C165948,
    and the tact switch footprint's pad numbering needs confirming - some 4-leg
    parts net-tie their pairs, which would mis-wire all 53 keys.
    Lands three alternative link connectors on the same six nets, of which exactly
    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
2026-07-28 docs: park J5 edge connector, keep J1 + J4, record the reasoning
    Rev A lands the 1x6 header (J1) and the EXT socket (J4). Both mount on the board
    face and change nothing about outline, plating or thickness, so carrying both
    costs nothing and lets one fabrication run serve either a soldered pigtail or an
    ordinary link cable.
    J5, the board-edge tongue, is dropped. It costs no parts but is not free: it
    forces an outline change, and an inserted edge wants ENIG at roughly 1.5-2.0x
    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
2026-07-28 docs: verify the pre-fab blockers against the real board, not the docs
    Checked the three blocking items with kicad-cli 10.0.5 and pcbnew, reading
    kicad/workboy.kicad_pcb directly instead of trusting what the checklist claimed.
    Two were false alarms, the third is worse than written, and two blockers were
    found that were not on the list at all.
    Resolved:
    - J3 USB-C pads. The premise was wrong on both counts: the netlist never used GCT
    USB4085 naming, and the shield is "SH" in both the netlist and the real
    footprint - no KiCad 10 Connector_USB footprint has an S1 pad. All 10 referenced
    pads exist and carry the intended net; the board's footprint copy is
    geometrically identical to the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
2026-07-28 feat(pcb): add four M2.5 mounting holes and re-export
    The board had none, while BUILD_PLAN promised 4x M2.5 and the case drilled four
    standoffs against hole positions that described a board that does not exist.
    H1-H4 are plain NPTH MountingHole_2.7mm_M2.5, 4.0 mm inset from the Edge.Cuts
    centreline at each corner, symmetric about the board centre (150.0, 89.0625):
    H1 ( 78.000, 40.000) H2 (222.000, 40.000)
    H3 ( 78.000, 138.125) H4 (222.000, 138.125) spacing 144.000 x 98.125 mm
    Positions were chosen by scanning clearance against every pad, track, via and part
    body rather than by eye. Insets of 4.0-5.5 mm all clear; 6.0 mm fails because the
    top-right hole starts fouling SW12. 4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
    [workboy-B_Courtyard.gbr, workboy-B_Cu.gbl, workboy-B_Fab.gbr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]
2026-07-28 docs: rev A ships J1 only - amend the link-connector decision to match the board
    The repo recorded a "land J1 + J4" decision it had never carried out.
    EMIT_LINK_SOCKET has always been False, so J4 never existed in any netlist or
    board. Rather than implement it, rev A formally ships J1 only.
    J4 is not free the way it first looked. It costs no board area, but it needs a
    footprint that does not exist and cannot be drawn without the physical socket in
    hand to measure. Drawing it, re-importing, re-placing, re-routing and re-exporting
    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
2026-07-28 fix(case): rebuild the case from the board file instead of the key field
    The case had never fitted any board, including the placeholder it claimed to fit.
    It sized itself from the KEY FIELD - LAYOUT_COLS * PITCH + margin - which has
    nothing to do with the PCB outline. That produced a 160 x 76 mm box with a
    155.2 x 71.2 mm interior for a 152.000 x 106.125 mm board: 34.9 mm short in depth,
    and 30 mm shallower than the board is deep even measured against the case's outer
    envelope. Its standoffs at (+/-61, +/-28.5) matched no hole on any board, and the
    placeholder's own 78 mm depth already exceeded the 71.2 mm interior, so the
    comment claiming it was "sized to sit inside the case interior" was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
2026-07-28 feat(pcb): move J3 USB-C to the right board edge and re-route
    J3 sat 16.07 mm inside the outline, so no USB-C plug could reach it - a case
    would have needed a 16 mm channel through the wall. It is now flush with the
    right edge, rotated 90 so the mating face points outward, body front on the
    outline and the courtyard overhanging by 0.525 mm as an edge connector should.
    Moving it exposed a second, latent problem. gen_pcb.py placed support parts with
    a row-wrapping flow, and the ["J3","R10","R11","D54"] group happened to straddle
    a wrap - stranding the CC2 pulldown and the VBUS Schottky ~130 mm away on the far
    side of the board and dragging the unfused power input across the whole PCB. That
    wa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
    [workboy-B_Courtyard.gbr, workboy-B_Cu.gbl, workboy-B_Fab.gbr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]
2026-07-28 fix(bom): C720477 was an SMD 4x3mm part - all 53 switches were unbuildable
    Checked on LCSC. C720477 is XUNPU TS-1088-AR02016, package "SMD,4x3mm", surface
    mount, 2 terminals. The board needs a 6x6 mm THROUGH-HOLE tact with 4 legs on
    Button_Switch_THT:SW_PUSH_6mm. Wrong size, wrong mount type, wrong terminal count -
    every one of the 53 switch lines specified a part that cannot be fitted.
    Replaced with C42416249, SHOU HAN SH-6X6X8H-CJ:
    package DIP-4P,6x6mm - through-hole, 4 legs
    lead spacing 6.5 x 4.5 mm - matches SW_PUSH_6mm exactly
    body 6 x 6 mm, 8 mm actuator
    rating SPST, 100,000 cycles, 50 mA, 12 V
    stock/price 8,480 in stock, ~$0.0124 ea at 20+ (about $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
    [workboy_jlcpcb_bom.csv]
2026-07-28 docs: record the live JLCPCB quote - the size penalty is $7.80, not a tier jump
    Quoted at 152 x 107 mm, 5 pcs, 2-layer, FR-4 TG135, 1.6 mm, HASL (with lead),
    1 oz, green, flying-probe tested:
    engineering fee $4.00
    board (5 pcs) $7.80
    build time 2 days $0.00
    PCB subtotal $11.80
    shipping $27.92 DHL Express (DDP), 2-4 business days, 0.40 kg
    total ~ $39.72
    This corrects the checklist, which warned the cheap tier "does not apply at all"
    because the board busts the 100 x 100 mm bracket on both axes. True, but the entire
    cost of that is the $7.80 board line: the same order at 100 x 100 quotes $4.00,
    where the board is free and you pay only the engineering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
2026-07-28 fix(bom): C2718 is a 500V MOSFET, not an ISP header - and cost the whole BOM
    Answering "does the $11.80 quote include the parts?" - it does not, it is five
    bare PCBs. Costing the components turned up a second bad part number.
    C2718, listed for J2 "2x3 ISP header 2.54mm", is onsemi FDA50N50: a 500 V, 48 A
    N-channel MOSFET, filed under Discrete Semiconductors > Transistors > FETs.
    Confirmed on the LCSC product page itself.
    Replaced with C42431837, JXTCONN PH2.54-2X3P-H25 - category Headers/Male Pins,
    2x3 six-pin dual row, 2.54 mm, through-hole, gold, 3 A / 1 kV, 39,180 in stock,
    $0.0293 at 20+.
    That is two of fourteen BOM lines pointing at parts that could not be fitted
    (C720477 was an SMD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
    [workboy_jlcpcb_bom.csv]
2026-07-28 fix(bom): audit every line - both LEDs were 0603 on an 0805 footprint
    Full audit of all 14 BOM lines against LCSC, checking identity, value, package AND
    availability rather than just that the part number resolves. Prompted by finding
    two outright wrong parts in a row.
    Two more errors found, both LEDs:
    C2286 was Hubei KENTO KT-0603R - 0603, board has 0805 pads
    C72043 was EVERLIGHT 19-217/GHC-YR1S2/3T - 0603, and unavailable
    The board uses LED_SMD:LED_0805_2012Metric. A 0603 body hand-solders onto 0805
    pads but risks tombstoning and misplacement in reflow, since pick-and-place
    positions to the part body rather than the pad. Replaced with the same
    manufacturer's genuine 0805 pa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
    [workboy_jlcpcb_bom.csv]
2026-07-28 fix(bom): re-spec the four 0402 resistors to in-stock YAGEO parts
    Last unbuyable lines. The UNI-ROYAL 0402WGF*TCE parts were the right value,
    package and tolerance but are out of stock at LCSC and absent from JLCPCB's
    assembly library. Replaced with the YAGEO RC0402FR-07 series, the standard 1%
    0402 jellybean, all deep in stock:
    R1-R3 10k C25744 -> C60490 RC0402FR-0710KL 1,233,200 in stock
    R4-R6 220R C25091 -> C112291 RC0402FR-07220RL 20,400 in stock
    R7-R9 1k C11702 -> C106235 RC0402FR-071KL 555,200 in stock
    R10,R11 5.1k C25905 -> C105872 RC0402FR-075K1L 1,443,500 in stock
    Identical spec to what they replace: 0402, +/-1%, 62.5 mW, 50 V, +/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
    [workboy_jlcpcb_bom.csv]
2026-07-28 fix(bom): check Basic vs Extended on JLCPCB - revert resistors to the Basic parts
    Checked every SMT part directly in JLCPCB's parts library. Result: 8 Basic, 4
    Extended. Extended parts carry a per-unique-part loading fee, which drives assembly
    cost more than the components themselves do.
    Basic C1525 100nF, C15850 10uF, C2480 SS14, C2297 green LED,
    C25744 10k, C25091 220R, C11702 1k, C25905 5.1k
    Extended C14877 ATmega, C2099 1N4148W, C165948 USB-C, C2295 red LED
    This reverses the previous commit's resistor swap, and the reason matters: the two
    catalogues disagree about the same parts.
    UNI-ROYAL 0402WGF*TCE out of stock at LCSC retail, but BASIC and stocked at JLCPC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
    [workboy_jlcpcb_bom.csv]
2026-07-28 docs: order 10 boards, not 5 - 28% cheaper per board for $26.75 more
    Quoted qty 10 at 152 x 107 mm, same specs (2-layer, FR-4 TG135, 1.6 mm, HASL with
    lead, 1 oz, green, flying-probe tested):
    engineering fee $ 4.00 (flat - does not scale)
    board (10 pcs) $15.60
    PCB subtotal $19.60
    shipping $28.06 DHL Express DDP (was $27.92 at qty 5 - up 14 cents)
    components $38.84 LCSC, volume breaks applied
    total $86.50 = $8.65 per board
    Against qty 5 at $59.75 / $11.95 per board: doubling the order costs $26.75 more
    and drops the unit price 28%. The five extra boards work out at about $5.35 each.
    The reason is entirely in the fixed cos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
2026-08-18 docs: de-personalize for public release
    SHOPPING_LIST.md was written to one builder's specific kit ("you already
    have", "per your call", a personal Amazon link) and noted holding the leaked
    DMGWYE ROM privately. It is now gitignored and kept local only; a generic
    "What you'll need to build one" section in README.md replaces it, carrying
    the parts, the ST-Link-won't-work warning, the link-connector options and the
    breadboard-first buying order.
    Also:
    - ship kicad/workboy_gerbers.zip instead of pointing at a gitignored file --
    JLCPCB takes a single zip, and three docs told you to upload one that was
    never in the repo.
    - drop two stale C:\workboy paths; the repo has never lived there.
    Co-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
2026-08-18 chore: move the ROM and TCRF PDFs into reference/, restructure .gitignore
    The leaked DMGWYE ROM, its .sav and the three Cutting Room Floor PDFs joined the
    emulators under reference/, so every piece of not-ours material now sits behind
    one ignore rule instead of five scattered ones, and the repo root holds only
    files the project actually ships.
    .gitignore is regrouped by *why* a thing is excluded rather than by what tool
    made it, and the reference/ block lists its expected contents so the rule is
    self-documenting. The DMGWYE-0.781.* and *.pdf wildcards are kept as redundant
    nets in case that material is ever dropped outside reference/.
    NOTICE now separates the two distinct reasons for exclu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
